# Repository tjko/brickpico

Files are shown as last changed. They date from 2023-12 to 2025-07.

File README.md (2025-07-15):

# Brickpico: Smart PWM LED Controller



Bricpico is a smart PWM LED controller based around [Raspberry Pi Pico](https://www.raspberrypi.com/documentation/microcontrollers/raspberry-pi-pico.html) (RP2040 MCU).
Brickpico is mainly meant to controlling various LED lights on LEGO models, but can be used to control any LED lights (or other small loads).

Brickpico operates as standalone controller that incorporates programmable timer to turn lights on/off on a schedule.
BrickPico is an Open-source hardware (OSHW) project.

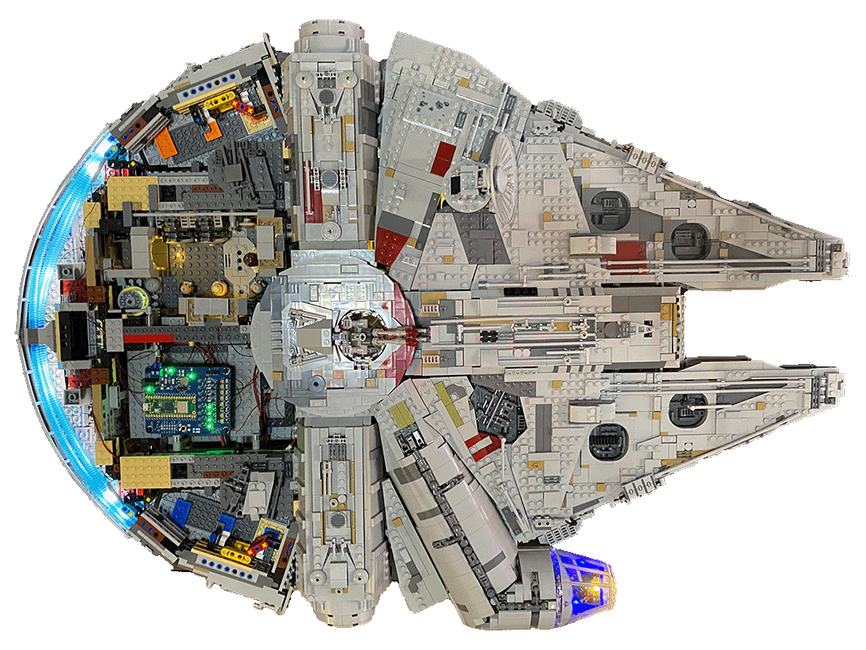
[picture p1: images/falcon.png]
LEGO Millennium Falcon


## Features
* Controls up to 8 to 16 separete channels (LED group)
* Adjustable output brightness (via PWM)
* Adjustable output voltage 5V or 3.3V
* Up to 200mA current output per port (each port has resettable fuse).
* Programmable PWM frequency from 10 to 100000 Hz
* Configurable Lightness/Gamma correction
* Support for configurable lighting "effects" on each channel
* Connectors for common Lego light kits (Light My Bricks, etc.) as well as 2.54mm pin header.
* I2C OLED display module support (128x64 or 128x128)
* I2C Enviromental sensor support (up to 8 sensors)
* Configuration stored on the device itself (in the flash memory).
* SCPI "like" programming interface (see [Command Reference](commands.md))
* WiFi support if opting to mount Pico W on the board.
* HTTP server for monitoring.
* MQTT support for sending status and to receive commands.
* Home Assistant (MQTT Discovery) support
* Telnet server for remote configuration and monitoring.
* SSH server for remote configuration and monitoring.

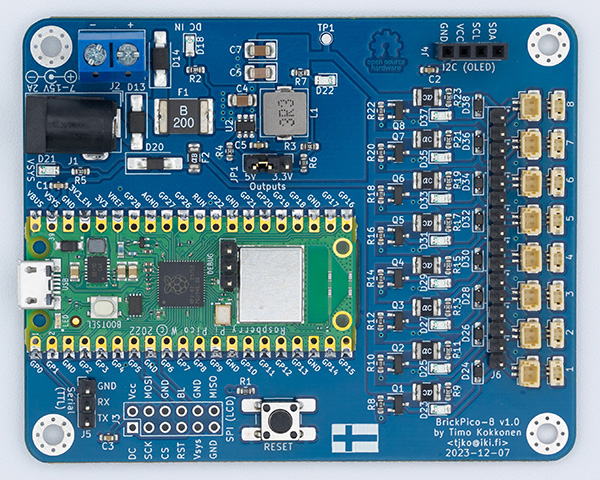
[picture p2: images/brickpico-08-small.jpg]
BrickPico


### Interfaces

* Serial "Console". Primary method for configuring/monitoring FanPico units is via (USB) Serial console (some units also have 3.3V TTL Serial connection).
* Telnet server allows configuration and monitoring over network.
* Web Interface (available when using _Pico W_) over WiFi

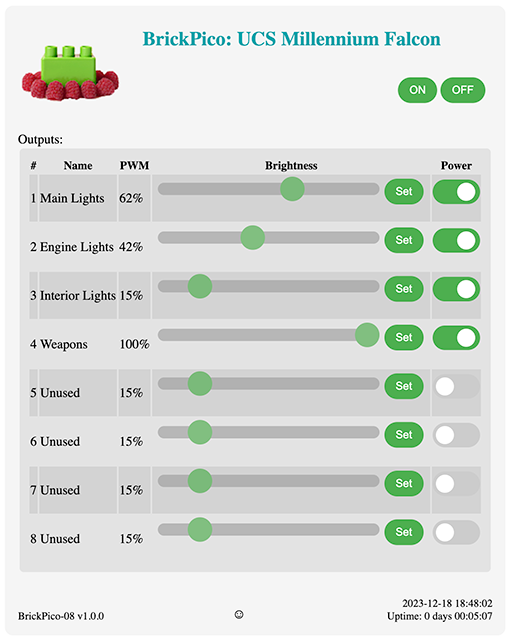
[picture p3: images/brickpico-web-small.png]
BrickPico
   

For more documentation check [BrickPico Wiki](https://github.com/tjko/brickpico/wiki)

## Where can I get one?
Initially BrickPico is only available as a DIY kit. For places to buy kits, check discussions: [Where to Buy BrickPico](https://github.com/tjko/brickpico/discussions/5)

(Instructions for building the kit can be found at: [BrickPico Wiki](https://github.com/tjko/brickpico/wiki)

### DIY Option
You can upload the Kerber files (found under boards directory) to your favorite PCB maker website and get your boards produced in matter of days.
Component list (BOM or bill of materials) is found under boards directory as well along with the electrical schematics.

### Review Units
If you are member of press (or YouTuber) and would like to review/test Brickpico. Please contact me via email.

## How Can I help?
* Build your own BrickPico and provide feedback, suggestions (see discussion forums).
* If you're into electronics new/improved board designs are most welcome.
* If you're into programming:
  - Create cool (desktop) program that allows easily configuring/controlling BrickPico boards.
  - Help improve the firmware.
* If you're into graphics (or web) design:
  - Help create cool (but lightweight) web interface
  - Create better logo for BrickPico
* As this is Open (Source) Hardware Project, if you like to build (and sell) assembled boards or DIY kits, you'd be most welcome...
* You can always donate (and get your name added to the Sponsors section, if you so wish).

## Hardware
BrickPico is Open Source Hardware, reference design is provided for the "08" model (8 outputs) and "16" model (16 outputs).

Additional models with different combinations of fan outputs could be easily designed (takining into account limitations of Raspberry Pi Pico I/O limits). New and improved PCB models/designs are most welcome.

BrickPico is loosely based on FanPico:
* [FanPico](https://github.com/tjko/fanpico/) - Open Source Smart PWM (PC) Fan Controller.

### Models (PCB designs)
Currently following models are available:

|Model|Outputs|Notes|
|-----|---|-----|
|[BRICKPICO-08](boards/brickpico-8/)|8||
|[BRICKPICO-16](boards/brickpico-16/)|16|PCB under development|

## Firmware
Firmware is developed in C using the Pico SDK. Pre-compiled firmware is released when there is new major features or bug fixes.

Latest pre-compiled firmware image can be found here: [Releases](https://github.com/tjko/brickpico/releases)

To get latest firmware with latest updates/fixes you must compile the firmware from the sources.

### Installing firmware image
Firmware can be installed via the built-in UF2 bootloader on the Raspberry Pi Pico or using the debug header with Picoprobe, etc...

#### Selecting Right Firmware to use
Each release (zip file) contains multiple different firmware files.
Make sure to select firmware for the board you're using and for the pico model ("pico_w" if using Pico W).

Firmware file names have format: brickpico-<board_model>-<pico_model>.uf2
```
brickpico-08-pico.uf2
brickpico-08-pico_w.uf2
brickpico-16-pico.uf2
brickpico-16-pico_w.uf2
```

#### Upgrading Firmware
Firmware upgrade steps:
* Boot Pico into UF2 bootloader. This can be done in two ways:
  1)  Press and hold "bootsel" button and then press and release "reset" button.
  2)  Issue command: SYS:UPGRADE
* Copy firmware file to the USB mass storage device that appears.
* As soon as firmware copy is complete, Pico will reboot and run the fanpico firmware.

### Building Firmware Images

Raspberry Pi Pico C/C++ SDK is required for compiling the firmware:

#### Requirements / Dependencies
* [Raspberry Pi Pico C/C++ SDK](https://www.raspberrypi.com/documentation/microcontrollers/c_sdk.html)
* [cJSON](https://github.com/DaveGamble/cJSON)
* [pico-lfs](https://github.com/tjko/pico-lfs)
* [ss_oled-lib](https://github.com/tjko/ss_oled-lib)
* [libb64](https://github.com/libb64/libb64)
* [pico-telnetd](https://github.com/tjko/pico-telnetd)

##### Install Pico SDK
Pico SDK must be installed working before you can compile fanpico.

Instructions on installing Pico SDK see: [Getting started with Raspberry Pi Pico](https://datasheets.raspberrypi.com/pico/getting-started-with-pico.pdf)

(Make sure PICO_SDK_PATH environment variable is set)

##### Downloading sources

Create some directory for building fanpico ('src' used in this example):
```
$ mkdir src
$ cd src
$ git clone https://github.com/tjko/brickpico.git
$ git submodule update --init --recursive
```

##### Building fanpico firmware

To build brickpico firmware, first create a build directory:
```
$ cd brickpico
$ mkdir build
```

Select which board to build firmware for (default is "08") and which Pico is to be used (default is "pico_w"):
```
$ cd build
$ cmake -DBRICKPICO_BOARD=16 -DPICO_BOARD=pico_w ..
```

Then compile fanpico:
```
$ make -j
```

After successful compile you should see firmware binary in the build directory:
subdirectory:

```
$ ls *.uf2
brickpico.uf2
```

If you have picotool installed you can check the firmware image information:
```
$ picotool info -a brickpico.uf2
File brickpico.uf2 family ID 'rp2040':

Program Information
 name:              brickpico
 version:           1.4.0beta
 web site:          https://github.com/tjko/brickpico/
 description:       BrickPico-08 - Smart LED Controller
 features:          USB stdin / stdout
 boot settings:     bootdelay = 0
                    safemode = 0
 binary start:      0x10000000
 binary end:        0x1010b638
 embedded drive:    0x101c0000-0x10200000 (256K): littlefs

Fixed Pin Information
 0:                 TX (Serial)
 1:                 RX (Serial)
 2:                 SCK (SPI)
 3:                 MOSI (SPI)
 4:                 MISO (SPI)
 5:                 CS (SPI)
 6:                 PWM7 signal (output)
 7:                 PWM8 signal (output)
 16:                PWM1 signal (output)
 17:                PWM2 signal (output)
 18:                PWM3 signal (output)
 19:                PWM4 signal (output)
 20:                PWM5 signal (output)
 21:                PWM6 signal (output)
 22:                LCD DC (SPI)
 26:                SDA (I2C)
 27:                SCL (I2C)
 28:                LCD Reset (SPI)

Build Information
 sdk version:       2.1.1
 pico_board:        pico_w
 boot2_name:        boot2_w25q080
 build date:        Jul 14 2025
 build attributes:  Release

Metadata Blocks
 none
```

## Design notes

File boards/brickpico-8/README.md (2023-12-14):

# BRICKPICO-08 PCB

PCB Size: 86mm x 79.5mm

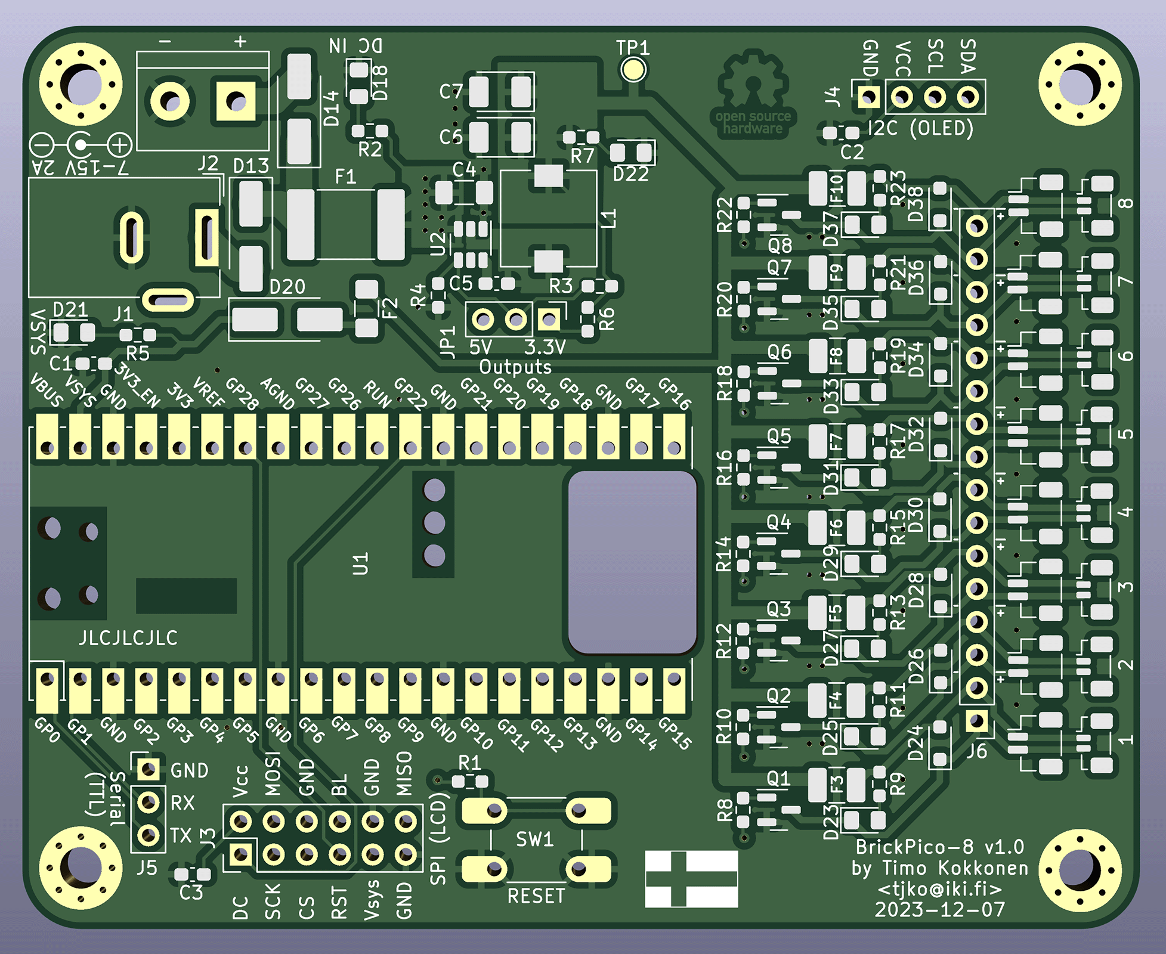
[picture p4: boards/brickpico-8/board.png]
PCB Render


## Change Log

v1.0 
- First Prototye

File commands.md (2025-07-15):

# BrickPico: Command Reference
BrickPico uses "SCPI like" command set. Command syntax should be mostly SCPI and IEE488.2 compliant,
to make it easier to control and configure Fanpico units.

## Command Set
BrickPico supports following commands:

* [*IDN?](#idn)
* [*RST](#rst)
* [CONFigure?](#configure)
* [CONFigure:DEFault:PWM](#configuredefaultpwm)
* [CONFigure:DEFault:STAte](#configuredefaultstate)
* [CONFigure:DELete](#configuredelete)
* [CONFigure:Read?](#configureread)
* [CONFigure:SAVe](#configuresave)
* [CONFigure:OUTPUTx:NAME](#configureoutputxname)
* [CONFigure:OUTPUTx:NAME?](#configureoutputxname-1)
* [CONFigure:OUTPUTx:EFFect](#configureoutputxeffect)
* [CONFigure:OUTPUTx:EFFect?](#configureoutputxeffect-1)
* [CONFigure:OUTPUTx:MINpwm](#configureoutputxminpwm)
* [CONFigure:OUTPUTx:MINpwm?](#configureoutputxminpwm-1)
* [CONFigure:OUTPUTx:MAXpwm](#configureoutputxmaxpwm)
* [CONFigure:OUTPUTx:MAXpwm?](#configureoutputxmaxpwm-1)
* [CONFigure:OUTPUTx:PWM](#configureoutputxpwm)
* [CONFigure:OUTPUTx:PWM?](#configureoutputxpwm-1)
* [CONFigure:OUTPUTx:STAte](#configureoutputxstate)
* [CONFigure:OUTPUTx:STAte?](#configureoutputxstate-1)
* [CONFigure:TIMERS?](#configuretimers)
* [CONFigure:TIMERS:ADD](#configuretimersadd)
* [CONFigure:TIMERS:DEL](#configuretimersdel)
* [CONFigure:VSENSORS?](#configurevsensors)
* [CONFigure:VSENSORS:SOUrces?](#configurevsensorssources)
* [CONFigure:VSENSORx:NAME](#configurevsensorxname)
* [CONFigure:VSENSORx:NAME?](#configurevsensorxname-1)
* [CONFigure:VSENSORx:SOUrce](#configurevsensorxsource)
* [CONFigure:VSENSORx:SOUrce?](#configurevsensorxsource-1)
* [MEASure:Read?](#measureread)
* [MEASure:OUTPUTx?](#measureoutputx)
* [MEASure:OUTPUTx:Read?](#measureoutputxread)
* [MEASure:OUTPUTx:PWM](#measureoutputxpwm)
* [MEASure:VSENSORS?](#measurevsensors)
* [MEASure:VSENSORx?](#measurevsensorx)
* [MEASure:VSENSORx:HUMidity?](#measurevsensorxhumidity)
* [MEASure:VSENSORx:PREssure?](#measurevsensorxpressure)
* [MEASure:VSENSORx:Read?](#measurevsensorxread)
* [MEASure:VSENSORx:TEMP?](#measurevsensorxtemp)
* [Read?](#read)
* [SYStem:ERRor?](#systemerror)
* [SYStem:DEBug](#systemdebug)
* [SYStem:DEBug?](#systemdebug-1)
* [SYStem:GAMMA](#systemgamma)
* [SYStem:GAMMA?](#systemgamma-1)
* [SYStem:LOG](#systemlog)
* [SYStem:LOG?](#systemlog-1)
* [SYStem:SYSLOG](#systemsyslog)
* [SYStem:SYSLOG?](#systemsyslog-1)
* [SYStem:DISPlay](#systemdisplay)
* [SYStem:DISPlay?](#systemdisplay)
* [SYStem:DISPlay:LAYOUTR](#systemdisplaylayoutr)
* [SYStem:DISPlay:LAYOUTR?](#systemdisplaylayoutr-1)
* [SYStem:DISPlay:LOGO](#systemdisplaylogo)
* [SYStem:DISPlay:LOGO?](#systemdisplaylogo-1)
* [SYStem:DISPlay:THEMe](#systemdisplaytheme)
* [SYStem:DISPlay:THEMe?](#systemdisplaytheme-1)
* [SYStem:ECHO](#systemecho)
* [SYStem:ECHO?](#systemecho-1)
* [SYStem:FLASH?](#systemflash)
* [SYStem:I2C?](#systemi2c)
* [SYStem:I2C:SCAN?](#systemi2cscan)
* [SYStem:I2C:SPEED](#systemi2cspeed)
* [SYStem:I2C:SPEED?](#systemi2cspeed?)
* [SYStem:OUTputs?](#systemoutputs)
* [SYStem:LED](#systemled)
* [SYStem:LED?](#systemled-1)
* [SYStem:LFS?](#systemlfs)
* [SYStem:LFS:COPY](#systemlfscopy)
* [SYStem:LFS:DELete](#systemlfsdelete)
* [SYStem:LFS:DIR?](#systemlfsdir)
* [SYStem:LFS:FORMAT](#systemlfsformat)
* [SYStem:LFS:REName](#systemlfsrename)
* [SYStem:MEM](#systemmem)
* [SYStem:MEM?](#systemmem-1)
* [SYStem:MQTT:SERVer](#systemmqttserver)
* [SYStem:MQTT:SERVer?](#systemmqttserver-1)
* [SYStem:MQTT:PORT](#systemmqttport)
* [SYStem:MQTT:PORT?](#systemmqttport-1)
* [SYStem:MQTT:USER](#systemmqttuser)
* [SYStem:MQTT:USER?](#systemmqttuser-1)
* [SYStem:MQTT:PASSword](#systemmqttpassword)
* [SYStem:MQTT:PASSword?](#systemmqttpassword-1)
* [SYStem:MQTT:SCPI](#systemmqttscpi)
* [SYStem:MQTT:SCPI?](#systemmqttscpi-1)
* [SYStem:MQTT:TLS](#systemmqtttls)
* [SYStem:MQTT:TLS?](#systemmqtttls-1)
* [SYStem:MQTT:HA:DISCovery](#systemmqtthadiscovery)
* [SYStem:MQTT:HA:DISCcovery?](#systemmqtthadiscovery-1)
* [SYStem:MQTT:INTerval:STATus](#systemmqttintervalstatus)
* [SYStem:MQTT:INTerval:STATus?](#systemmqttintervalstatus-1)
* [SYStem:MQTT:INTerval:TEMP](#systemmqttintervaltemp)
* [SYStem:MQTT:INTerval:TEMP?](#systemmqttintervaltemp-1)
* [SYStem:MQTT:INTerval:PWM](#systemmqttintervalpwm)
* [SYStem:MQTT:INTerval:PWM?](#systemmqttintervalpwm-1)
* [SYStem:MQTT:TOPIC:STATus](#systemmqtttopicstatus)
* [SYStem:MQTT:TOPIC:STATus?](#systemmqtttopicstatus-1)
* [SYStem:MQTT:TOPIC:COMMand](#systemmqtttopiccommand)
* [SYStem:MQTT:TOPIC:COMMand?](#systemmqtttopiccommand-1)
* [SYStem:MQTT:TOPIC:RESPonse](#systemmqtttopicresponse)
* [SYStem:MQTT:TOPIC:RESPonse?](#systemmqtttopicresponse-1)
* [SYStem:MQTT:TOPIC:ERRor](#systemmqtttopicerror)
* [SYStem:MQTT:TOPIC:ERRor?](#systemmqtttopicerror-1)
* [SYStem:MQTT:TOPIC:WARNing](#systemmqtttopicwarning)
* [SYStem:MQTT:TOPIC:WARNing?](#systemmqtttopicwarning-1)
* [SYStem:MQTT:TOPIC:TEMP](#systemmqtttopictemp)
* [SYStem:MQTT:TOPIC:TEMP?](#systemmqtttopictemp-1)
* [SYStem:MQTT:TOPIC:PWM](#systemmqtttopicpwm)
* [SYStem:MQTT:TOPIC:PWM?](#systemmqtttopicpwm-1)
* [SYStem:NAME](#systemname)
* [SYStem:NAME?](#systemname-1)
* [SYStem:PWMfreq](#systempwmfreq)
* [SYStem:PWMfreq?](#systempwmfreq-1)
* [SYStem:SERIAL](#systemserial)
* [SYStem:SERIAL?](#systemserial-1)
* [SYStem:SPI](#systemspi)
* [SYStem:SPI?](#systemspi-1)
* [SYStem:SSH:SERVer](#systemsshserver)
* [SYStem:SSH:SERVer?](#systemsshserver-1)
* [SYStem:SSH:AUTH](#systemsshauth)
* [SYStem:SSH:AUTH?](#systemsshauth-1)
* [SYStem:SSH:PORT](#systemsshport)
* [SYStem:SSH:PORT?](#systemsshport-1)
* [SYStem:SSH:USER](#systemsshuser)
* [SYStem:SSH:USER?](#systemsshuser-1)
* [SYStem:SSH:PASSword](#systemsshpassword)
* [SYStem:SSH:PASSword?](#systemsshpassword-1)
* [SYStem:SSH:KEY?](#systemsshkey)
* [SYStem:SSH:KEY:CREate](#systemsshkeycreate)
* [SYStem:SSH:KEY:DELete](#systemsshkeydelete)
* [SYStem:SSH:KEY:LIST?](#systemsshkeylist)
* [SYStem:SSH:PUBKEY?](#systemsshpubkey)
* [SYStem:SSH:PUBKEY:ADD](#systemsshpubkeyadd)
* [SYStem:SSH:PUBKEY:DELete](#systemsshpubkeydelete)
* [SYStem:SSH:PUBKEY:LIST?](#systemsshpubkeylist)
* [SYStem:TELNET:SERVer](#systemtelnetserver)
* [SYStem:TELNET:SERVer?](#systemtelnetserver-1)
* [SYStem:TELNET:AUTH](#systemtelnetauth)
* [SYStem:TELNET:AUTH?](#systemtelnetauth-1)
* [SYStem:TELNET:PORT](#systemtelnetport)
* [SYStem:TELNET:PORT?](#systemtelnetport-1)
* [SYStem:TELNET:RAWmode](#systemtelnetrawmode)
* [SYStem:TELNET:RAWmode?](#systemtelnetrawmode-1)
* [SYStem:TELNET:USER](#systemtelnetuser)
* [SYStem:TELNET:USER?](#systemtelnetuser-1)
* [SYStem:TELNET:PASSword](#systemtelnetpassword)
* [SYStem:TELNET:PASSword?](#systemtelnetpassword-1)
* [SYStem:TIME](#systemtime)
* [SYStem:TIME?](#systemtime-1)
* [SYStem:TIMEZONE](#systemtimezone)
* [SYStem:TIMEZONE?](#systemtimezone-1)
* [SYStem:TLS:CERT](#systemtlscert)
* [SYStem:TLS:CERT?](#systemtlscert-1)
* [SYStem:TLS:PKEY](#systemtlspkey)
* [SYStem:TLS:PKEY?](#systemtlspkey-1)
* [SYStem:UPTIme?](#systemuptime)
* [SYStem:UPGRADE](#systemupgrade)
* [SYStem:VERsion?](#systemversion)
* [SYStem:VSENSORS?](#systemvsensors)
* [SYStem:WIFI?](#systemwifi)
* [SYStem:WIFI:AUTHmode](#systemwifiauthmode)
* [SYStem:WIFI:AUTHmode?](#systemwifiauthmode-1)
* [SYStem:WIFI:COUntry](#systemwificountry)
* [SYStem:WIFI:COUntry?](#systemwificountry-1)
* [SYStem:WIFI:HOSTname](#systemwifihostname)
* [SYStem:WIFI:HOSTname?](#systemwifihostname-1)
* [SYStem:WIFI:IPaddress](#systemwifiipaddress)
* [SYStem:WIFI:IPaddress?](#systemwifiipaddress-1)
* [SYStem:WIFI:MODE](#systemwifimode)
* [SYStem:WIFI:MODE?](#systemwifimode-1)
* [SYStem:WIFI:NETMASK](#systemwifinetmask)
* [SYStem:WIFI:NETMASK?](#systemwifinetmask-1)
* [SYStem:WIFI:GATEWAY](#systemwifigateway)
* [SYStem:WIFI:GATEWAY?](#systemwifigateway-1)
* [SYStem:WIFI:NTP](#systemwifintp)
* [SYStem:WIFI:NTP?](#systemwifintp-1)
* [SYStem:WIFI:SYSLOG](#systemwifisyslog)
* [SYStem:WIFI:SYSLOG?](#systemwifisyslog-1)
* [SYStem:WIFI:MAC?](#systemwifimac)
* [SYStem:WIFI:SSID](#systemwifissid)
* [SYStem:WIFI:SSID?](#systemwifissid-1)
* [SYStem:WIFI:STATus?](#systemwifistatus)
* [SYStem:WIFI:STATS?](#systemwifistats)
* [SYStem:WIFI:PASSword](#systemwifipassword)
* [SYStem:WIFI:PASSword?](#systemwifipassword-1)
* [WRIte:OUTPUTx](#writeoutputx)
* [WRIte:OUTPUTx:PWM](#writeoutputxpwm)
* [WRIte:OUTPUTx:STAte](#writeoutputxstate)
* [WRIte:VSENSORx](#writevsensorx)

Additionally unit will respond to following standard SCPI commands to provide compatibility in case some program
unconditionally will send these:
* *CLS
* *ESE
* *ESE?
* *ESR?
* *OPC
* *OPC?
* *SRE
* *SRE?
* *STB?
* *TST?
* *WAI

### Common Commands

#### *IDN?
Identify device. This returns string that contains following fields:
```
<manufacturer>,<model number>,<serial number>,<firmware version>
```

Example:
```
*IDN?
TJKO Industries,BRICKPICO-16,e660c0d1c768a330,1.0
```

#### *RST
Reset unit. This triggers BrickPico to perform (warm) reboot.

```
*RST
```

### CONFigure:
Commands for configuring the device settings.

#### CONFigure?
Display current configuration in JSON format.
Same as CONFigure:Read?

Example:
```
CONF?
```

#### CONFigure:DEFault:PWM
Copy current output PWM (brightess) settings to power-on default PWM settings.
Alternative to this command is to set default PWM for each port using _CONF:OUTPUTx:PWM_ command.

Configuration must be saved after running this command.

Example:
```
CONF:DEFAULT:PWM
CONF:SAVE
```

#### CONFigure:DEFault:STAte
Copy current output states (ON/OFF) to power-on default states.
Alternative to this command is to set default power on state using _CONF:OUTPUTx:DEFAULT_ command.

Configuration must be saved after running this command.

Example:
```
CONF:DEFAULT:STATE
CONF:SAVE
```

#### CONFigure:DELete
Delete current configuration saved into flash. After unit has been reset it will be using default configuration.

Example:
```
CONF:DEL
*RST
```

#### CONFigure:Read?
Display current configuration in JSON format.

Example:
```
CONF:READ?
```

#### CONFigure:SAVe
Save current configuration into flash memory.

Example:
```
CONF:SAVE
```

### CONFigure:OUTPUTx Commands
OUTPUTx commands are used to configure specific output port.
Where x is a number for the output port.

For example:
```
CONFIGURE:OUTPUT8:NAME Interrior Lights
```

#### CONFigure:OUTPUTx:NAME
Set name for output port.

For example:
```
CONF:OUTPUT1:NAME Front Lights
```

#### CONFigure:OUTPUTx:NAME?
Query name of a output port.

For example:
```
CONF:OUTPUT1:NAME?
Front Lights
```

#### CONFigure:OUTPUTx:EFFect
Configure active effect for an ouput channgel.

Effect|Description|Arguments|Argument Descriptions|Default|Notes
------|-----------|---------|---------------------|-------|-------
none|No effect|||
fade|Fade in/out when channgel is toggled on/off.|fade_in_time,fade_out_time|Fade-in and fade-out times in seconds.|fade,1.0,1.0|
blink|Blink output at specified rate.|on_time,off_time|Light on and off times in seconds.|blink,0.5,1.5|
pulse|Pulse output|fade_in_time,on_time,fade_out_time,off_time|Define duration of each 4 sections of a pulse "cycle" inseconds.|fade,2.0,0.5,2.0,0.5|

For example (configur blinking using defaults):
```
CONF:OUTPUT1:EFF blink
```

For example (configure blinking with custom parameters):
```
CONF:OUTPUT1:EFF blink,1.0,2.5
```

#### CONFigure:OUTPUTx:EFFect?
Display currently active effect for an output.

Format: effect,arg_1,arg_2,...arg_n

For example:
```
CONF:OUTPUT1:EFF?
blink,0.500000,1.500000
```

#### CONFigure:OUTPUTx:MINpwm
Set absolute minimum PWM duty cycle (%) for given output port.
This can be used to make sure that output never sees a lower
duty cycle (overriding the normal signal).

Default: 0 %

Example: Set minimum PWM duty cycle to 20% for OUTPUT1
```
CONF:OUTPUT1:MIN 20
```

#### CONFigure:OUTPUTx:MINpwm?
Query current minimum PWM duty cycle (%) configured on a output port.

Example:
```
CONF:OUTPUT1:MIN?
20
```

#### CONFigure:OUTPUTx:MAXpwm
Set absolute maximum PWM duty cycle (%) for given output port.
This can be used to make sure that output never sees higher duty cycle
than given value (overriding the normal output signal).

Default: 100 %

Example: Set maximum PWM duty cycle to 95% for OUTPUT1
```
CONF:OUTPUT1:MAX 95
```

#### CONFigure:OUTPUTx:MAXpwm?
Query current maximum PWM duty cycle (%) configured on a output port.

Example:
```
CONF:OUTPUT1:MAX?
95
```

#### CONFigure:OUTPUTx:PWM
Set default PWM duty cycle (%) for given output port.
This is value set when unit boots up and normally defaults
to 100% (full brightness).

Default: 100%

Example: Set default PWM duty cycle to 50% for OUTPUT1
```
CONF:OUTPUT1:PWM 50
```

#### CONFigure:OUTPUTx:PWM?
Query current default PWM duty cycle for an output port.

Example:
```
CONF:OUTPUT1:PWM?
50
```

#### CONFigure:OUTPUTx:STAte
Controls whether output is ON or OFF state when unit boots up.

Values: ON, OFF

Default: OFF

Example: Set Output 5 to be ON when system boots up.
```
CONF:OUTPUT5:STATE ON
```

#### CONFigure:OUTPUTx:STAte?
Query whether output is set to default to ON or OFF when unit boots up.

Example:
```
CONF:OUTPUT1:STATE?
OFF
```

#### CONFigure:TIMERS?
List currently configured timers (events).

Output format:
```
<#>: <minute> <hour> <weekdays> <action> <outputs> <comment>
```

Example:
```
CONF:TIMERS?
1: 00 18 1-5 ON 1-6 turn on lights during the week
1: 00 17 6-7 ON 1-6 turn on lights on the weekends
2: 30 05 0-6 OFF 1-16 turn off lights in the morning
```

#### CONFigure:TIMERS:ADD
Add new timer entry.

Timer entry format:
```
<minute> <hour> <weekdays> <action> <outputs> [<comment>]
```

Field|Valid Values|Description
-----|------|-----
minute|00..59|Minute
hour|00.23|Hour (24h clock)
weekdays|0..6|0=Sunday, 1=Monday, 2=Tuesday, ... 6=Saturday
action|ON, OFF|
outputs|1..n|Outputs that the event affects.

Specifying _weekdays_ and _outputs_:

Notation|Description
--------|-----------
*|Match all
1,3,5|List
1-5|Range

Example:
```
CONF:TIMERS:ADD 00 18 1-5 ON 1-6 Turn on during the week
CONF:TIMERS:ADD 00 17 6-7 ON 1-8 Turn on during weekends
CONF:TIMERS:ADD 00 06 * OFF * Turn everything off in the morning 
```

#### CONFigure:TIMERS:DEL
Remove timer event. Command takes the event number as parameter.
Currently configured timer events along with their numbers can be
viewed using: _CONF:TIMERS?_

Example (remove second timer event):
```
CONF:TIMERS:DEL 2
```

#### CONFigure:VSENSORS?

This is same as CONFigure::VSENSORS:SOUrces? command.

#### CONFigure:VSENSORS:SOUrces?
Return virtual sensor (source) configuration information for all
virtual sensors in CSV format.

Format: <vsensor>,<type>,<parameter1>,<parameter2>,...

Example:
```
CONF:VSENSORS:SOURCES?
vsensor1,picotemp
vsensor2,i2c,0x48,TMP117
vsensor3,i2c,0x37,PCT2075
vsensor4,i2c,0x77,DPS310
vsensor5,i2c,0x76,BMP280
vsensor6,i2c,0x49,ADT7410
vsensor7,i2c,0x38,AHT2x
vsensor8,manual,0.00,30
```

### CONFigure:VSENSORx Commands
VSENSORx (where x is the sensor number) commands are used to configure virtual temperature sensors.
These can be "sensors" that are updated by software, like "CPU Temperature" of host system.
Or these can be be virtual sensors that report value of multiple physical sensors fed through a mathematical formula.

Where x is a number from 1 to 8.

Virtual Sensor Mode|Description
------|-----------
manual|Manually updated (by software) sensor values. For example host CPU Temperature.
max|Maximum temperature of configured source sensors.
min|Minimum temperature of configured source sensors.
avg|Average temperature of configured source sensors.
delta|Temperature delta between readings from two source sensors.
i2c|Reading from digital I2C sensor.
picotemp|Pico (MCU) Temperature.

#### CONFigure:VSENSORx:NAME
Set name for virtual temperature sensor.

For example:
```
CONF:VSENSOR1:NAME Pico Temperature
```

#### CONFigure:VSENSORx:NAME?
Query name of a virtual temperature sensor.

For example:
```
CONF:VSENSOR1:NAME?
Pico Temperature
```

#### CONFigure:VSENSORx:SOUrce
Configure source for the virtual temperature sensor.

Source types:

MODE|Description|No of Parameters|Parameters
----|-----------|----------------|----------
MANUAL|Temperature updated by external program/driver|2|default_temperature_C,timeout
MAX|Maximum temperatore between source sensors|2+|sensor_a,sensor_b, ...
MIN|Minimum temperature between source sensors|2+|sensor_a,sensor_b, ...
AVG|Average temperature between source sensors|2+|sensor_a,sensor_b, ...
DELTA|Temperature delta between to source sensors|2|sensor_a,sensor_b
I2C|Temperature reading from digital I2C sensor|2|i2c_address,sensor_type_or_alias
PICOTEMP|Pico (MCU) temperature|0|

Note, in "manual" mode if timeout_ms is set to zero, then sensor's temperature reading
will never revert back to default value (if no updates are being received).

Sensor numbering:
 - VSENSORS: 1, 2, ...
 - PICO Temperature: 101

Supported I2C sensors:

Sensor Type|Aliases|Possible Addresses|Description|Notes
-----------|-------|------------------|-----------|-----
ADT7410||0x48, 0x49, 0x4a, 0x4b|16bit Digital Temperature Sensor, 0.5C accuracy
AHT1x|||AHT1x Series Temperature and Humidity sensors (AHT10, AHT11 ,...)
AHT2x|||AHT2x Series Temperature and Humidity sensors (AHT20, AHT21 ,...)
AM2320||0x5c|Temperature and Humidity Sensor, 0.5C accuracy|Not found when scanning bus. May not work above 100kHz bus speeds.
AS621x|AS6212, AS6214, AS6218||AS621x Series sensors: AS6212 (0.2C), AS6214 (0.4C), AC6218 (0.8C)
BMP180|||16bit, 0.5C accuracy
BMP280||0x76, 0x77|20bit, 0.5C accuracy
DPS310||0x77, 0x76|24bit, 0.5C accuracy
HDC302x|HDC3022, HDC3021, HDC3020|0x44, 0x45, 0x46, 0x47|HDC302x Series Temperature and Humiditysensors
HTS221||0x5f|Temperature and Humidity Sensor
HTU21D||0x40|Temperature and Humidity Sensor, 0.4C accuracy|Not found when scanning bus (SYS:I2C:SCAN?)
HTU31D||0x40, 0x41|Temperature and Humidity Sensor, 0.3C accuracy
LPSxx|LPS22, LPS25, LPS28, LPS33, LPS35|0x5d, 0x5c|LPSxx Series Temperature and Pressure sensors
MCP9808|||Digital Temperature Sensor, 0.5C accuracy
MPL115A2||0x60|Digital Barometer|Temperature sensor not calibrated.
MPL3115A2||0x60|Temperature and Pressure sensor with Altimetry, 1C accuracy
MS5611||0x76, 0x77|Temperature and Pressure Sensor|Not found when scanning bus (SYS:I2C:SCAN?)
MS8607||0x76 and 0x40|Temperature, Humidity and Pressure Sensor|Not found when scanning bus (SYS:I2C:SCAN?), appears as two seprate devices.
PCT2075|||Digital Temperature Sensor, 1C accuracy
SHT3x|SHT30, SHT31, SHT35|0x44, 0x34|SHT3x Series Temperature and Humidity sensors|Not always found when scanning bus (SYS:I2C:SCAN?)
SHT4x|SHT40, SHT41, SHT43, SHT45|0x44|SHT4x Series Temperature and Humidity sensors|Not always found when scanning bus (SYS:I2C:SCAN?)
SHTC3||0x70|Temperature and Humidity sensor, 0.2C accuracy
SI7021||0x40|Temperature and Humidity sensor, 0.4C accuracy
STTS22H||0x38, 0x3c, 0x3e, 0x3f|Temperature Sensor, 0.5C accuracy
TC74|TC74A0|0x48 - 0x4f|Digital Thermal Sensor, 2C accuracy
TMP102||0x48, 0x49, 0x4a, 0x4b|Temperature Sensor, 2C accuracy
TMP117||0x48, 0x49, 0x4a, 0x4b|Temperature Sensor, 0.1C accuracy

Defaults:

Default for all virtual sensors is to be in "MANUAL" mode and revert automatically to 0C
if no temperature update has been received within 30 seconds.

VSENSOR|SOURCE
---|------
1|MANUAL,0,30
...|...

Example: Set VSENSOR1 to report temperature that is updated by external program. And to sensor reading to revert to default value of 99C if no update has been received within 5 seconds.
```
CONF:VSENSOR2:SOURCE manual,99,5
```

Example: Set VSENSOR2 to follow report temperature delta between SENSOR1 and SENSOR2.
```
CONF:VSENSOR2:SOURCE delta,1,2
```

Example: Set VSENSOR3 to report average temperature between SENSOR1, SENSOR2, and VSENSOR1
```
CONF:VSENSOR3:SOURCE avg,1,2,101
```

Example: Set VSENSOR5 to report temperature from TMP117 (I2C) sensor with address 0x48:
```
CONF:VSENSOR5:SOURCE i2c,0x48,tmp117
```

(to get list of currently active I2C sensor addresses, use: SYS:I2C:SCAN?)

#### CONFigure:VSENSORx:SOUrce?
Query a virtual temperature sensor configuration (temperature reading source).

Command returns response in following format:
```
mode,parameter,parameter,...
```

Example:
```
CONF:VSENSOR1:SOU?
manual,99.0,5
```

### MEASure Commands
These commands are for reading (measuring) the current output values on ports.

#### MEASure:Read?
This command returns current output settings on all OUTPUT ports.
(This is same as: Read?)

Response format:
```
output<n>,"<name>",<output duty cycle>,<output state>
```

Example:
```
MEAS:READ?
output1,"Output 1",100.0,OFF
output2,"Output 2",50.00,OFF
output3,"Output 3",50.00,ON
output4,"Output 4",25.00,ON
...
```

### MEASure:OUTPUTx Commands

#### MEASure:OUTPUTx?
Return current output PWM signal duty cycle (%) for a output.

Response format:
```
<duty_cycle>
```

Example:
```
MEAS:OUTPUT1?
100.00
```

#### MEASure:OUTPUTx:Read?
Return current output PWM signal duty cycle (%) for a output.

This is same as: MEASure:OUTPUTx?

#### MEASure:OUTPUTx:PWM?
Return current output PWM signal duty cycle (%) for a output.

This is same as: MEASure:OUTPUTx?

#### MEASure:VSENSORS?
Return all measurements for all virtual sensors.

Format: sensor,temperature_C,humidity_%,pressure_hPa

Example:
```
MEAS:VSENSORS?
vsensor1,"vsensor1",24.4,0,0
vsensor2,"vsensor2",24.9,0,0
vsensor3,"vsensor3",24.8,43,0
vsensor4,"vsensor4",26.5,0,997
vsensor5,"vsensor5",25.1,0,991
vsensor6,"vsensor6",0.0,0,0
vsensor7,"vsensor7",0.0,0,0
vsensor8,"vsensor8",0.0,0,0
```

#### MEASure:VENSORx?
Return current temperature (C) measured by the sensor.

Example:
```
MEAS:VSENSOR1?
25
```

#### MEASure:VSENSORx:HUMidity?
Return current humidity (%) measured by the sensor.

Example:
```
MEAS:VSENSOR1:HUM?
45
```

#### MEASure:VSENSORx:PREssure?
Return current pressure (hPa) measured by the sensor.

Example:
```
MEAS:VSENSOR1:PRE?
1013
```

#### MEASure:VSENSORx:Read?
Return current temperature (C) measured by the sensor.

This is same as: MEASure:VSENSORx?

Example:
```
MEAS:VSENSOR1:R?
25
```

#### MEASure:VSENSORx:TEMP?
Return current temperature (C) measured by the sensor.

This is same as: MEASure:VSENSORx?

Example:
```
MEAS:VSENSOR1:TEMP?
25
```

### Read Commands

#### Read?
This command returns all setting for all OUTPUT ports.
(This is same as: MEASure:Read?)

Response format:
```
output<n>,"<name>",<output duty cycle>
```

Example:
```
MEAS:READ?
output1,"Output 1",100.0
output2,"Output 2",50.00
output3,"Output 3",50.00
output4,"Output 4",0.00
...
```

### SYStem Commands

#### SYStem:ERRor?
Display status from last command.

Example:
```
SYS:ERR?
0,"No Error"
```

#### SYStem:DEBug
Set the system debug level. This controls the logging to the console.

Default: 0   (do not log any debug messages)

Example: Enable verbose debug output
```
SYS:DEBUG 2
```

#### SYStem:DEBug?
Display current system debug level.

Example:
```
SYS:DEBUG?
0
```

#### SYStem:GAMMA
Set system PWM output mapping (Lightness/Gamma correction).

Light output from LED lights normally does not correlate linearly
to PWM duty cycle. PWM output mapping can be used to "correct" this
to produce more linear light (output) compared to PWM duty cycle.

Value|Description|Value Range|Example
---------------|-----------|-----------|------
\<number\>|Gamma correction factor (valid range 1.0 - 10.0)|2.5
cie|CIE (1931) Lightness algorithm|N/A|cie
\<blank\>|Use default correction|N/A|

Default: <blank>   (use default correction method; currently CIE 1931)

Example: Set output PWM mapping to use Gamma 2.2 correction factor
```
SYS:GAMMA 2.2
```

#### SYStem:GAMMA?
Display current system PWM output mapping (Lightness/Gamma correction).

Value|Description
-----|----------
1.0|Gamma correction factor 1.0 (no correction)
2.2|Gamma correction factor 2.2 (slightly under corrected)
2.5|Gamma correction factor 2.5 (normal correction)
cie|Use CIE 1931 Lightness algorithm
\<blank\>|Use default correction (currently "cie")

Example:
```
SYS:GAMMA?
2.5
```

#### SYStem:LOG
Set the system logging level. This controls the level of logging to the console.

Default: WARNING

Log Levels:

Level|Name
-----|----
0|EMERG
1|ALERT
2|CRIT
3|ERR
4|WARNING
5|NOTICE
6|INFO
7|DEBUG

Example: Enable verbose debug output
```
SYS:LOG DEBUG
```

#### SYStem:LOG?
Display current system logging level.

Example:
```
SYS:LOG?
NOTICE
```

#### SYStem:SYSLOG
Set the syslog logging level. This controls the level of logging to a remote
syslog server.

Default: ERR

Log Levels:

Level|Name
-----|----
0|EMERG
1|ALERT
2|CRIT
3|ERR
4|WARNING
5|NOTICE
6|INFO
7|DEBUG

Example: Enable logging of NOTICE (and lower level) message:
```
SYS:LOG NOTICE
```

#### SYStem:SYSLOG?
Display current syslog logging level.

Example:
```
SYS:SYSLOG?
ERR
```

#### SYStem:DISPlay
Set display (module) parameters as a comma separated list.

This can be used to set display module type if cannot be automatically detected.
Additionally this can be used to set some display parameters like brightness.

Default: default

Currently supported values:

Value|Description|Notes
-----|-----------|-----
default|Use default settings (auto-detect).
128x64|OLED 128x64 module installed.|OLED
128x128|OLED 128x128 module installed.|OLED
132x64|OLED 132x64 installed (some 1.3" 128x64 modules need this setting!)|OLED
flip|Flip display (upside down)|OLED
invert|Invert display|OLED
brightness=n|Set display brightness (%) to n (where n=0..100) [default: 50]|OLED

Example: 1.3" (SH1106) module installed that doesn't get detected correctly
```
SYS:DISP 132x64
```

Example: Invert display and set brightnes to 30%
```
SYS:DISP default,invert,brightness=30
```

#### SYStem:DISPlay?
Display current display module setting.

Example:
```
SYS:DISP?
132x64,flip,invert,brightness=75
```

#### SYStem:DISPlay:LAYOUTR
Configure (OLED) Display layout for the right side of the screen.

Layout is specified as a comma delimited string describing what to
display on each row (8 rows available if using 128x64 OLEd module, 10 rows available with 128x128 pixel modules).

Syntax: <R1>,<R2>,...<R8>

Where tow specifications can be one of the following:

Type|Description|Notes
----|-----------|-----
Mn|MBFan input n|n=1..4
Sn|Sensor input n|n=1..3
Vn|Virtual Sensor input n|n=1..8
-|Horizontal Line|
Ltext|Line with "text"|Max length 9 characters.

Default: <not set>

When this setting is not set following defaults are used based
on the OLED module size:

Screen Size|Available Rows|Default Configuration
-----------|--------------|---------------------
128x64|8|M1,M2,M3,M4,-,S1,S2,S3
128x128|10|LMB Inputs,M1,M2,M3,M4,-,LSensors,S1,S2,S3

Example: configure custom theme (for 128x64 display):
```
SYS:DISP:LAYOUTR M1,M2,-,S1,S2,S3,V1,V2
```

#### SYStem:DISPlay:LAYOUTR?
Display currently configured (OLED) Display layout for the right side of the screen.

Example:
```
SYS:DISP:THEME?
M1,M2,-,S1,S2,S3,V1,V2
```

#### SYStem:DISPlay:LOGO
Configure (LCD) Display boot logo.

Currently available logos:

Name|Description
----|-----------
default|Default FanPico boot logo.
custom|Custom boot logo (only available if firmware has been compiled with custom logo included).

Example: configure custom logo
```
SYS:DISP:LOGO custom
```

#### SYStem:DISPlay:LOGO?
Display currently configured (LCD) Display boot logo.

Example:
```
SYS:DISP:LOGO?
default
```

#### SYStem:DISPlay:THEMe
Configure (LCD) Display theme to use.

Default: default

Example: configure custom theme
```
SYS:DISP:THEME custom
```

#### SYStem:DISPlay:THEMe?
Display currently configured (LCD) display theme name.

Example:
```
SYS:DISP:THEME?
default
```

#### SYStem:ECHO
Enable or disaple local echo on the console.
This can be useful if interactively programming BrickPico.

Value|Status
-----|------
0|Local Echo disabled.
1|Local Echo enabled.

Default: 0

Example: enable local echo
```
SYS:ECHO 1
```

Example: disable local echo
```
SYS:ECHO 0
```

#### SYStem:ECHO?
Display local echo status:

Example:
```
SYS:ECHO?
0
```

### SYStem:FLASH?
Returns information about Pico flash memory usage.

Example:
```
SYS:FLASH?
Flash memory size:                     2097152
Binary size:                           683520
LittleFS size:                         262144
Unused flash memory:                   1151488
```

### SYStem:I2C?
Returns status if I2C bus is active (available) currently.
Depending on board model I2C may not be available at all
or may only be available if SPI is not active.

Returns:

status|description
------|-----------
0|I2C Bus not available
1|I2C Bus available

Example:
```
SYS:I2C?
1
```

### SYStem:I2C:SCAN?
Scan I2C Bus for active devices.
This returns addresses of any devices found on I2C bus.

Example:
```
SYS:I2C:SCAN??
Scanning I2C Bus... 0x3c
Device(s) found: 1
```

### SYStem:I2C:SPEED
Set speed that I2C bus operates.
Note, change won't take effect until unit is rebooted.

Speed range: 10000 - 3400000
(speeds over 1000000 may not work reliably)

Default: 1000000  (1000 kHz or 1000 kbit/s)

Example:
```
SYS:I2C:SPEED 1000000
CONF:SAVE
```

### SYStem:I2C:SPEED?
Return currently configured I2C bus speed (Hz or bit/s).

Example:
```
SYS:I2C:SPEED?
1000000
```

#### SYStem:OUTPUTS?
Display number of OUTPUT output ports available.

Example:
```
SYS:OUTPUTS?
8
```

#### SYStem:LED
Set system indicator LED operating mode.

Supported modes:

mode|description
----|-----------
0   | LED blinking slowly  [default]
1   | LED on (continuously)
2   | LED off

Default: 0

Example to set LED to be on continuously:
```
SYS:LED 1
```

#### SYStem:LED?
Query current system LED operating mode.

Example:
```
SYS:LED?
0
```

#### SYStem:LFS?
Display information about the LittleFS filesystem in the flash memory.

Example:
```
SYS:LFS?
Filesystem size:                       262144
Filesystem used:                       24576
Filesystem free:                       237568
Number of files:                       3
Number of subdirectories:              0
```

#### SYStem:LFS:COPY
Copy a file on the flash filesystem (littlefs).
If destination file already exists copy will fail.

Parameters: <sourcefile> <destinationfile>

Example:
```
SYS:LFS:COPY fanpico.cfg fanpico-backup.cfg
```

#### SYStem:LFS:DELete
Delete file from the flash filesystem (littlefs).

parameters: <filename>

Example (delete TLS certificate and private key):
```
SYS:LFS:DEL cert.pem
SYS:LFS:DEL key.pem
```

#### SYStem:LFS:DIR?
List contents of the flash filesystem (littlefs).

Example:
```
SYS:LFS:DIR?
Directory: /

.                                                       <DIR>
..                                                      <DIR>
cert.pem                                                 1286
fanpico.cfg                                              7012
key.pem                                                  1709

```

#### SYStem:LFS:FORMAT
Format flash filesystem. This will erase current configuration (including any TLS certificates saved in flash).

Example (format filesystem and save current configuration):
```
SYS:LFS:FORMAT
CONF:SAVE
```

#### SYStem:LFS:REName
Rename a file on the flash filesystem (littlefs).

Parameters: <oldname> <newname>

Example:
```
SYS:LFS:REN fanpico-backup.cfg fanpico.cfg
```

### SYStem:MEM
Test how much available (heap) memory system currently has.
This does simple test to try to determine what is the largest
block of heap memory that is currently available as well as
try allocating as many as possible small block of memory to determine
roughly the total available heap memory.

This command takes optional 'blocksize' parameter to specify the memory
block size to use in the tests. Default is 1024 bytes.

Example:
```
SYS:MEM 512
Largest available memory block:        114688 bytes
Total available memory:                111104 bytes (217 x 512bytes)
```

### SYStem:MEM?
Returns information about heap and stack size. As well as information
about current (heap) memory usage as returned by _mallinfo()_ system call.

Note,  _mallinfo()_ doesn't "see" all of the available heap memory, unless ```SYS:MEM``` command
has been run first.

Example:
```
SYS:MEM?
Core0 stack size:                      8192
Core1 stack size:                      4096
Heap size:                             136604
mallinfo:
Total non-mmapped bytes (arena):       136604
# of free chunks (ordblks):            2
# of free fastbin blocks (smblks):     0
# of mapped regions (hblks):           0
Bytes in mapped regions (hblkhd):      0
Max. total allocated space (usmblks):  0
Free bytes held in fastbins (fsmblks): 0
Total allocated space (uordblks):      21044
Total free space (fordblks):           115560
Topmost releasable block (keepcost):   114808
```

### SYStem:MQTT Commands
BrickPico has MQTT Client that can be configured to publish (send) periodic status
updates to a topic.
Additionally MQTT Client support subscribing to a "command" topic to listen for commands.
This allows remotely controlling BrickPico.

To enable MQTT at minimum server must be configured. To explicitly disbable MQTT set server
to empty string.

#### SYStem:MQTT:SERVer
Set MQTT server to connect to. This parameter expects a DNS name as argument.

Default: <empty>   (when this setting is empty string, MQTT is explicitly disabled)

Example (configure MQTT server name):
```
SYS:MQTT:SERVER io.adafruit.com
```

Example (disable MQTT):
```
SYS:MQTT:SERVER
```

#### SYStem:MQTT:SERVer?
Query currently set MQTT server name.

Example:
```
SYS:MQTT:SERVER?
io.adafruit.com
```

#### SYStem:MQTT:PORT
Set MQTT server (TCP) port. This setting is needed when MQTT server is not using standard port.
If this setting is not set (value is left to default "0"), then standard MQTT port is used.

- Secure (TLS) Port = 8883
- Insecure Port = 1883

Default: 0   (when this setting is 0 use default MQTT ports)

Example:
```
SYS:MQTT:PORT 9883
```

#### SYStem:MQTT:PORT?
Query currently set MQTT (TCP) port.

If return value is zero (0), then default MQTT port is being used.

Example:
```
SYS:MQTT:PORT?
0
```

#### SYStem:MQTT:USER
Set MQTT username to use when connecting to MQTT server.

Default: <empty>

Example:
```
SYS:MQTT:USER myusername
```

#### SYStem:MQTT:USER?
Query currently set MQTT username.

Example:
```
SYS:MQTT:USER?
myusername
```

#### SYStem:MQTT:PASS
Set MQTT password to use when connecting to MQTT server.

Default: <empty>

Example:
```
SYS:MQTT:PASS mymqttpassword
```

#### SYStem:MQTT:PASS?
Query currently set MQTT password.

Example:
```
SYS:MQTT:PASS?
mymqttpassword
```

#### SYStem:MQTT:SCPI
Configure if SCPI commands will be accepted via MQTT.
This is potentially "dangerous" feature so only enable if you understand
the potential risks allowing device to be remotely configured.

Default: OFF

Example:
```
SYS:MQTT:SCPI ON
```

#### SYStem:MQTT:SCPI?
Query whether SCPI commands are allowed via MQTT.

Example:
```
SYS:MQTT:SCPI?
OFF
```

#### SYStem:MQTT:TLS
Enable/disable use of secure connection mode (TLS/SSL) when connecting to MQTT server.
Default is TLS on to protect MQTT credentials (usename/password).

Default: ON

Example:
```
SYS:MQTT:TLS OFF
```

#### SYStem:MQTT:TLS?
Query whether TLS is enabled or disabled for MQTT.

Example:
```
SYS:MQTT:TLS?
ON
```

#### SYStem:MQTT:HA:DISCovery
Configure Home Assistant MQTT Discovery prefix. This must be set to enable
Home Assistant support/integration in BrickPico.

If this is left to empty (string), then Home Assistant support is disabled.

Default: <empty>

Example (enable Home Assistant support using default prefix):
```
SYS:MQTT:HA:DISC homeassistant
```

#### SYStem:MQTT:HA:DISCovery?
Query currently set Home Assistant MQTT Discovery prefix.

Note, if this is empty, then Home Assistant support is disabled.

Example:
```
SYS:MQTT:HA:DISC?
homeassistant
```

#### SYStem:MQTT:INTerval:STATus
Configure how often unit will publish (send) status message to status topic.
Set this to 0 (seconds) to disable publishing status updates.
Recommended values are 60 (seconds) or higher.

Default: 600  (every 10 minutes)

Example:
```
SYS:MQTT:INT:STAT 3600
```

#### SYStem:MQTT:INTerval:STATus?
Query currently set frequency for publishing unit status information.

Example:
```
SYS:MQTT:INT:STAT?
3600
```

#### SYStem:MQTT:INTerval:TEMP
Configure how often unit will publish (send) status message to temp topic.
Set this to 0 (seconds) to disable publishing temperature updates.
Recommended values are 60 (seconds) or higher.

Default: 60  (every 60 seconds)

Example:
```
SYS:MQTT:INT:TEMP 180
```

#### SYStem:MQTT:INTerval:TEMP?
Query currently set frequency for publishing unit temperature information.

Example:
```
SYS:MQTT:INT:TEMP?
180
```

#### SYStem:MQTT:INTerval:PWM
Configure how often unit will publish (send) status message to PWM topic.
Set this to 0 (seconds) to disable publishing PWM updates.
Recommended values are 60 (seconds) or higher.

Default: 600  (every 10 minutes)

Example:
```
SYS:MQTT:INT:PWM 300
```

#### SYStem:MQTT:INTerval:PWM?
Query currently set frequency for publishing unit PWM information.

Example:
```
SYS:MQTT:INT:PWM?
300
```

#### SYStem:MQTT:TOPIC:STATus
Configure topic to publish unit status information periodically.
If this is left to empty (string), then no status information is published to MQTT server.

Default: <empty>

Example:
```
SYS:MQTT:TOPIC:STAT musername/feeds/brickpico1
```

#### SYStem:MQTT:TOPIC:STATus?
Query currently set topic for publishing unit status information to.

Example:
```
SYS:MQTT:TOPIC:STAT?
myusername/feeds/brickpico1
```

#### SYStem:MQTT:TOPIC:COMMand
Configure topic to subscribe to to wait for commands to control outputs.
If this is left to empty (string), then unit won't subcrible (and accept) any commands from MQTT.

Default: <empty>

Example:
```
SYS:MQTT:TOPIC:COMM musername/feeds/cmd
```

#### SYStem:MQTT:TOPIC:COMMand?
Query currently set topic for subscribing to wait for commands.

Example:
```
SYS:MQTT:TOPIC:COMM?
myusername/feeds/cmd
```

#### SYStem:MQTT:TOPIC:RESPonse
Configure topic to publish responses to commands received from the command topic.
If this is left to empty, then unit won't send response to any commands.

Default: <empty>

Example:
```
SYS:MQTT:TOPIC:RESP musername/feeds/response
```

#### SYStem:MQTT:TOPIC:RESPonse?
Query currently set topic for publishing responses to commands.

Example:
```
SYS:MQTT:TOPIC:RESP?
myusername/feeds/response
```

#### SYStem:MQTT:TOPIC:ERRor
Configure topic to subscribe to for receiving error messages from MQTT broker.

Default: <empty>

Example:
```
SYS:MQTT:TOPIC:ERR mysername/errors
```

#### SYStem:MQTT:TOPIC:ERRor?
Query currently set topic for subscribing to receive error messages from MQTT broker.

Example:
```
SYS:MQTT:TOPIC:ERR?
myusername/errors
```

#### SYStem:MQTT:TOPIC:WARNing
Configure topic to subscribe to for receiving warning messages from MQTT broker.

Default: <empty>

Example:
```
SYS:MQTT:TOPIC:WARN mysername/throttle
```

#### SYStem:MQTT:TOPIC:WARNing?
Query currently set topic for subscribing to receive warning messages from MQTT broker.

Example:
```
SYS:MQTT:TOPIC:WARN?
myusername/throttle
```

#### SYStem:MQTT:TOPIC:TEMP
Configure topic to publish unit temperature data to.

Default: <empty>

Example:
```
SYS:MQTT:TOPIC:TEMP mysername/feeds/brickpico_temp
```

#### SYStem:MQTT:TOPIC:TEMP?
Query currently set topic for publishing temperature data.

Example:
```
SYS:MQTT:TOPIC:TEMP?
myusername/feeds/brickpico_temp
```

#### SYStem:MQTT:TOPIC:PWM
Configure topic to publish output port PWM status to.
This is a template string where ```%d``` should be used to mark the output port number.

Default: <empty>

Example:
```
SYS:MQTT:TOPIC:PWM mysername/feeds/brickpico_output%d
```

#### SYStem:MQTT:TOPIC:PWM?
Query currently set topic for publishing PWM data.

Example:
```
SYS:MQTT:TOPIC:PWM?
myusername/feeds/brickpico_output%d
```

#### SYStem:NAME
Set name of the system. (Default: fanpico1)

Example:
```
SYS:NAME HomeServer
```

#### SYStem:NAME?
Get name of the system.

Example:
```
SYS:NAME?
HomeServer
```

#### SYStem:PWMfreq
Set PWM frequency for the outputs. Supported range 10Hz - 100kHz.
When changing the frequency, chang will take effect after unit has been rebooted.

Default: 1000  (1kHz)

Example, set PWM frequency to 1.5kHz:
```
SYS:PWM 1500
CONF:SAVE
*RST
```

#### SYStem:PWMfreq?
Get current PWM frequency for the outputs.

Example:
```
SYS:PWM?
1000
```

#### SYStem:SERIAL
Enable or disable TTL Serial Console. This is enabled by default if board has this connector.
Reason to disable this could be to use the second I2C bus that is sharing pins with the UART.

Example (disable serial console):
```
SYS:SERIAL 0
```

#### SYStem:SERIAL?
Return status of TTL Serial Console.

Status|Description
------|-----------
1|Enabled
0|Disabled

Example:
```
SYS:SERIAL?
1
```

#### SYStem:SPI
Enable or disable SPI bus (on connector J18). When SPI bus is enabled I22 (OLED display) and Serial TTL connectors cannot be used
as these share pins with the SPI bus.
Reason to enable SPI bus would be to connect LCD panel on the J18 connector.

Example (enable SPI bus):
```
SYS:SPI 1
```

#### SYStem:SPI?
Return status of SPI bus.

Status|Description
------|-----------
1|Enabled
0|Disabled

Example:
```
SYS:SPI?
0
```

### SSH Server Commands

#### SYStem:SSH:SERVer
Control whether SSH server is enabled or not.
After making change configuration needs to be saved and unit reset.

Default: OFF

Example:
```
SYS:SSH:SERV ON
```

#### SYStem:SSH:SERVer?
Display whether SSH server status.

Example:
```
SYS:SSH:SERV?
OFF
```

#### SYStem:SSH:AUTH
Toggle SSH server authentication mode. When enabled then SSH server will
require user to authenticate (password or publickey authentication).
When off, no authentication is needed.

Default: ON

Example:
```
SYS:SSH:AUTH OFF
```

#### SYStem:SSH:AUTH?
Display whether SSH server authentication is enabled or not.

Example:
```
SYS:SSH:AUTH?
ON
```

#### SYStem:SSH:PORT
Set TCP port where SSH server will listen on.
If this setting is not set then default port will be used.

Default: 22 (default SSH port)

Example:
```
SYS:SSH:PORT 8022
```

#### SYStem:SSH:PORT?
Display currently configured port for SSH server.

(if port is set to 0, then default Telnet port will be used)

Example:
```
SYS:SSH:PORT?
8022
```

#### SYStem:SSH:USER
Configure username that is allowed to login to this server using SSH.

When no username is set, password authentication is disabled.

Default: <none>

Example (set username):
```
SYS:SSH:USER admin
```

Example (remove username):
```
SYS:SSH:USER
```

#### SYStem:SSH:USER?
Display currently configured SSH user (login) name.

When no username is set, password authentication is disabled.

Example:
```
SYS:SSH:USER?
admin
```

#### SYStem:SSH:PASSword
Configure password for the SSH user. Password is hashed using SHA-512 Crypt algorithm.

Default: <none>

Example (set passwod):
```
SYS:SSH:PASS mypassword
```

Example (remove password):
```
SYS:SSH:PASS
```

#### SYStem:SSH:PASSword?
Display currently configured SSH user password hash.

When no password is set, password authentication is disabled.

Example:
```
SYS:SSH:PASS?
$6$QvD5AkWSuydeH/EB$UsYA0cymsCRSse78fN4bMb5q0hM5B7YUNSFd3zJfMDbTG7DOH8iuMufVjsvqBOxR9YCJYSHno4CFeOhLtTGLx.
```

#### SYStem:SSH:KEY?
Display list of server private keys. Currently there is no support to
extract/export private keys. This command only displays SHA256 checksums for
each key.

Example:
```
SYS:SSH:KEY?
ecdsa                     121 SHA256:bDd9a2FrWRCyGxwgNZzzejEh+0ivXkww6nbM+4cIfSg
ed25519                    82 SHA256:/si832zNTkrxn0MHh8dhwfa6KlDAPcTRHsoqZbeVaSM
```

#### SYStem:SSH:KEY:CREate
Create SSH Server Private Key. Generated key is saved on the filesystem (littlefs) and
is used by the SSH server as its server private key.

Command takes key type as parameter.

Currently supported key types:

 - ECDSA
 - ED25519
 - ALL (create all supported keys)

Example:
```
SYS:SSH:KEY:CREATE ED25519
Generating ed25519 private key...
OK
```

#### SYStem:SSH:KEY:DELete
Delete SSH Server Private key. Key is deleted from the internal filesystem (littlefs).
When rotating server keys, old key must be first removed, before new one can be created.

Command takes key type as parameter.

Example:
```
SYS:SSH:KEY:DEL ECDSA
Deleting ecdsa private key...
Private key deleted.
```

#### SYStem:SSH:KEY:LIST?
Display list of server private keys.
This is same as command SYS:SSH:KEY?

#### SYStem:SSH:PUBKEY?
Display list of user name and public key pairs that can be used to login
using publicky authentication.

Example:
```
SYS:SSH:PUBKEY?
1: admin ssh-ed25519 AAAAC3NzaC1lZDI1NTE5AAAAIOOWu9+yEevReQUXEDgEMAIrs1DERTwZeSRRhIqioC6x admin@ws1
2: testuser ecdsa-sha2-nistp256 AAAAE2VjZHNhLXNoYTItbmlzdHAyNTYAAAAIbmlzdHAyNTYAAABBBH+E8WDRmrU2fKizKDyQXdLj3YGh7w5Wl7F2clpzHvGWIoBAJ/nsyUpMCqujzG7eD0EOKukBcb6vqyf2IQ96GLU= testuser@localhost
```

#### SYStem:SSH:PUBKEY:ADD
Add SSH public key for user to authenticate with.
Command takes two parameters "username", and "public key" (in OpenSSH format).
Currently up to 4 pubic keys can be added.

Parameters: <username> <ssh publickey>

Example:
```
SYS:SSH:PUBKEY ADD amdin ssh-ed25519 AAAAC3NzaC1lZDI1NTE5AAAAIOOWu9+yEevReQUXEDgEMAIrs1DERTwZeSRRhIqioC6x admin@ws1
SSH Public key added: slot 1: ssh-ed25519 (admin)
```

#### SYStem:SSH:PUBKEY:DELete
Delete SSH Public key.

Parameters: <key number>

(Command SYS:SSH:PUBKEY? can be used to find out key numbers.)

Example:
```
SYS:SSH:PUBKEY:DEL 1
SSH Public key deleted: slot 1: admin:ssh-ed25519 (admin@ws1)
```

#### SYStem:SSH:PUBKEY:LIST?
Display list of user name and public key pairs that can be used to login
This is same as SYS:SSH:PUBKEY?

### Telnet Server Commands

#### SYStem:TELNET:SERVer
Control whether Telnet server is enabled or not.
After making change configuration needs to be saved and unit reset.

Default: OFF

Example:
```
SYS:TELNET:SERV ON
```

#### SYStem:TELNET:SERVer?
Display whether Telnet server status.

Example:
```
SYS:TELNET:SERV?
OFF
```

#### SYStem:TELNET:AUTH
Toggle Telnet server authentication mode. When enabled then Telnet server will
prompt user for login/password. When off, no authentication is needed.

Default: ON

Example:
```
SYS:TELNET:AUTH OFF
```

#### SYStem:TELNET:AUTH?
Display whether Telnet server authentication is enabled or not.

Example:
```
SYS:TELNET:AUTH?
ON
```

#### SYStem:TELNET:PORT
Set TCP port where Telnet server will listen on.
If this setting is not set then default port will be used.

Default: 23 (default Telnet port)

Example:
```
SYS:TELNET:PORT 8000
```

#### SYStem:TELNET:PORT?
Display currently configured port for Telnet server.

(if port is set to 0, then default Telnet port will be used)

Example:
```
SYS:TELNET:PORT?
8000
```

#### SYStem:TELNET:RAWmode
Configure Telnet server mode. By default Telnet server uses Telnet protocol, but
setting this option causes Telnet protocol to be disabled. And server uses "raw TCP" mode.

Default: OFF

Example:
```
SYS:TELNET:RAW ON
```

#### SYStem:TELNET:RAWmode?
Display if "raw TCP" mode is enabled or not.

Example:
```
SYS:TELNET:RAW?
OFF
```

#### SYStem:TELNET:USER
Configure username that is allowed to login to this server using Telnet.

Default: <none>

Example:
```
SYS:TELNET:USER admin
```

#### SYStem:TELNET:USER?
Display currently configured telnet user (login) name.

Example:
```
SYS:TELNET:USER?
admin
```

#### SYStem:TELNET:PASSword
Configure password for the telnet user. Password is hashed using SHA-512 Crypt algorithm.

Default: <none>

Example:
```
SYS:TELNET:PASS mypassword
```

#### SYStem:TELNET:PASSword?
Display currently configured telnet user password hash.

Example:
```
SYS:TELNET:PASS?
$6$QvD5AkWSuydeH/EB$UsYA0cymsCRSse78fN4bMb5q0hM5B7YUNSFd3zJfMDbTG7DOH8iuMufVjsvqBOxR9YCJYSHno4CFeOhLtTGLx.
```

#### SYStem:TIME
Set system Real-Time Clock (RTC) time.

This command expects time in following format:
  YYYY-MM-DD HH:MM:SS

Example:
```
SYS:TIME 2022-09-19 18:55:42
```

#### SYStem:TIME?
Return current Real-Time Clock (RTC) time.
This is only available if using Pico W and it has successfully
gotten time from a NTP server or RTC has been initialized using
SYStem:TIME command.

Command returns nothing if RTC has not been initialized.

Example:
```
SYS:TIME?
2022-09-19 18:55:42
```

#### SYStem:TIMEZONE
Set POSIX timezone to use when getting time from a NTP server.
If DHCP server does not supply POSIX Timezone (DHCP Option 100), then this
command can be used to specify local timezone.

This command takes POSIX timezone string as argument (or if argument is blank,
then it clears existinh timezone setting).

Example (set Pacific Standard time as local timezone):
```
SYS:TIMEZONE PST8PDT7,M3.2.0/2,M11.1.0/02:00:00
```

Example (clear timezone setting):
```
SYS:TIMEZONE
```

#### SYStem:TIMEZONE?
Return current POSIX timezone setting.

Command returns nothing if no timezone has been set.

Example:
```
SYS:TIMEZONE?
PST8PDT7,M3.2.0/2,M11.1.0/02:00:00
```

#### SYStem:TLS:CERT
Upload or delete TLS certificate for the HTTP server.
Note, both certificate and private key must be installed before HTTPS server will
activate (when system is restarted next time).

When run without arguments this will prompt to paste TLS (X.509) certificate
in PEM format.  When run with "DELETE" argument currently installed certificate
will be deleted.

Example (upload/paste certificate):
```
SYS:TLS:CERT
Paste certificate in PEM format:

```

Example (delete existing certificate from flash memory):
```
SYS:TLS:CERT DELETE
```

#### SYStem:TLS:CERT?
Display currently installed certificate.

Example:
```
SYS:TLS:CERT?
```

#### SYStem:TLS:PKEY
Upload or delete (TLS Certificate) Private key for the HTTP server.
Note, both certificate and private key must be installed before HTTPS server will
activate (when system is restarted next time).

When run without arguments this will prompt to paste private key
in PEM format.  When run with "DELETE" argument currently installed private key
will be deleted.

Example (upload/paste private key):
```
SYS:TLS:PKEY
Paste private key in PEM format:

```

Example (delete existing private key from flash memory):
```
SYS:TLS:PKEY DELETE
```

#### SYStem:TLS:PKEY?
Display currently installed private key.

Example:
```
SYS:TLS:CERT?
```

#### SYStem:UPTIme?
Return time elapsed since unit was last rebooted.

Example:
```
SYS:UPTIME?
up 4 days, 22 hours, 27 minutes
```

#### SYStem:UPGRADE
Reboot unit to USB (BOOTSEL) mode for firmware upgrade.
This command triggers fanpico to reboot and enter USB "mode", where
new firmware can simply be copied to the USB drive that appears.
After file has been copied, fanpico will automatically reboot to new
firmware image.

Example:
```
SYS:VER?
```

#### SYStem:VERsion?
Display software version and copyright information.

Example:
```
SYS:VER?
```

#### SYStem:VSENSORS?
Display number of virtual (temperature) sensors available.

Example:
```
SYS:VSENSORS?
8
```

#### SYStem:WIFI?
Check if the unit support WiFi networking.
This should be used to determine if any other "WIFI"
commands will be available.

Return values:

0 = No WiFi support (Pico).
1 = WiFi supported (Pico W).

Example:
```
SYS:WIFI?
1
```

#### SYStem:WIFI:AUTHmode
Set Wi-Fi Authentication mode.

Following modes are currently supported:

Mode|Description|Notes
----|-----------|-----
default|Use system default|Currently default is WPA2
WPA3_WPA2|Use WPA3/WPA2 (mixed) mode|
WPA3|Use WPA3 only|
WPA2|Use WPA2 only|
WPA2_WPA|Use WPA2/WPA (mixed) mode|
WPA|Use WPA only|
OPEN|Use "Open" mode|No authentication.

Example:
```
SYS:WIFI:AUTH WPA3_WPA2
```

#### SYStem:WIFI:AUTHmode?
Return currently configured Authentication mode for the WiFi interface.

Example:

```
SYS:WIFI:AUTH?
default
```

#### SYStem:WIFI:COUntry
Set Wi-Fi Country code. By default, the country setting for the wireless adapter is unset.
This means driver will use default world-wide safe setting, which can mean that some channels
are unavailable.

Country codes are two letter (ISO 3166) codes. For example, Finland = FI, Great Britain = GB,
United States of Americ = US, ...

Example:
```
SYS:WIFI:COUNTRY US
```

#### SYStem:WIFI:COUntry?
Return currently configured country code for the Wi-Fi interface.

Codes used are the ISO 3166 standard two letter codes ('XX' means unset/worldwide setting).

Example:

```
SYS:WIFI:COUNTRY?
US
```

#### SYStem:WIFI:HOSTname
Set system hostname. This will be used with DHCP and SYSLOG.
If hostname is not defined then system will default to generating
hostname as follows:
  BrickPico-xxxxxxxxxxxxxxxx

(where "xxxxxxxxxxxxxxxx" is the BrickPico serial number)

Example:
```
SYS:WIFI:HOSTNAME fanpico1
```

#### SYStem:WIFI:HOSTname?
Return currently configured system hostname.

Example:

```
SYS:WIFI:HOSTNAME?
fanpico1
```

#### SYStem:WIFI:IPaddress
Set staticlly configured IP address.

Set address to "0.0.0.0" to enable DHCP.

Example:

```
SYS:WIFI:IP 192.168.1.42
```

#### SYStem:WIFI:IPaddress?
Display currently configured (static) IP address.
If no static address is configured, DHCP will be used.

Set address to "0.0.0.0" to enable DHCP.

Example:

```
SYS:WIFI:IP?
0.0.0.0
```

#### SYStem:WIFI:MODE
Set WiFi connection mode. Normally this setting is not needed with modern APs.

However, if FanPico is failing to connect to WiFi network, this couldbe
due to old firmware on the AP (upgrading to latest firmware typically helps).
If firmware update did not help or there is no updated firmware available, setting
connection mode to synchronous can help (however this could cause FanPico to "hang" for up to 60 seconds
during boot up).

Mode|Description
------|-----------
0|Asynchronous connection mode (default)
1|Synchronous connection mode

Default: 0

Example:

```
SYS:WIFI:MODE 1
```

#### SYStem:WIFI:MODE?
Display currently configured WiFi connection mode?

Example:

```
SYS:WIFI:MODE?
0

```

#### SYStem:WIFI:NETMASK
Set statically configured netmask.

Example:

```
SYS:WIFI:NETMASK 255.255.255.0
```

#### SYStem:WIFI:NETMASK?
Display currently configured (static) netmask.

Example:

```
SYS:WIFI:NETMASK?
255.255.255.0
```

#### SYStem:WIFI:GATEWAY
Set statically configured default gateway (router).

Example:

```
SYS:WIFI:GATEWAY 192.168.1.1
```

#### SYStem:WIFI:GATEWAY?
Display currently configured default gateway (router).

Example:

```
SYS:WIFI:GATEWAY?
192.168.1.1
```

#### SYStem:WIFI:NTP
Configure IP for NTP server to use.

Set to "0.0.0.0" to use server provided by DHCP.

Example:

```
SYS:WIFI:NTP 192.168.1.10
```

#### SYStem:WIFI:NTP?
Display currently configure NTP server.

Note, "0.0.0.0" means to use DHCP.

Example:

```
SYS:WIFI:NTP?
192.168.1.10
```

#### SYStem:WIFI:SYSLOG
Configure IP for Syslog server to use.

Set to "0.0.0.0" to use server provided by DHCP.

Example:

```
SYS:WIFI:SYSLOG 192.168.1.20
```

#### SYStem:WIFI:SYSLOG?
Display currently configured Syslog server.

Note, "0.0.0.0" means to use DHCP.

Example:

```
SYS:WIFI:SYSLOG?
192.168.1.20
```

#### SYStem:WIFI:MAC?
Display WiFi adapter MAC (Ethernet) address.

Example:

```
SYS:WIFI:MAC?
28:cd:c1:01:02:03
```

#### SYStem:WIFI:SSID
Set Wi-Fi network SSID. FanPico will automatically try joining to this network.

Example
```
SYS:WIFI:SSID mynetwork
```

#### SYStem:WIFI:SSID?
Display currently configured Wi-Fi network SSID.

Example:

```
SYS:WIFI:SSID?
mynetwork
```

#### SYStem:WIFI:STATus?
Display WiFi Link status.

Return value: linkstatus,current_ip,current_netmask,current_gateway

Link Status:

Value|Description
-----|-----------
0    |Link is down.
1    |Connected to WiFi.
2    |Connected to WiFi, but no IP address.
3    |Connected to WiFi with and IP address.
-1   |Connection failed.
-2   |No matching SSID found(could be out of range, or down).
-3   |Authentication failed (wrong password?)

Example:

```
SYS:WIFI:STAT?
1,192.168.1.42,255.255.255.0,192.168.1.1
```

#### SYStem:WIFI:STATS?
Display TCP/IP stack (LwIP) statistics.

NOTE, this command only works on "Debug" builds of the firmware currently.

Example
```
SYS:WIFI:STATS?
```

#### SYStem:WIFI:PASSword
Set Wi-Fi (PSK) password/passrase.

Example
```
SYS:WIFI:PASS mynetworkpassword
```

#### SYStem:WIFI:PASSword?
Display currently configured Wi-Fi (PSK) password/passphrase.

Example:

```
SYS:WIFI:PASS?
mynetworkpassword
```

### WRIte Commands

These commands are for turning output ports ON/OFF and for adjusting output PWM duty cycle.

#### WRIte:OUTPUTx

Turn output on or off.

Example: Turn OUTPUT1 on.
```
WRITE:OUTPUT1 ON
```

Example: Turn OUTPUT1 off.
```
WRITE:OUTPUT1 OFF
```

#### WRIte:OUTPUTx:PWM

Set output PWM duty cycle. Valid values are from 0 to 100.

Example: Set OUTPUT2 to 25% duty cycle.
```
WRITE:OUTPUT2:PWM 25
```

#### WRIte:OUTPUTx:STAte

Turn output  on or off. This is same as WRIte:OUTPUTx command.

Example: Turn OUTPUT1 on.
```
WRITE:OUTPUT1:STATE ON
```

Example: Turn OUTPUT1 off.
```
WRITE:OUTPUT1:STATE OFF
```

#### WRIte:VSENSORx

Set/update temperature of a virtual sensor. This can be used by a program on the host
system to feed external temperature information into BrickPico.

Example: Set VSENSOR1 temperature to 42.1C
```
WRITE:VSENSOR1 42.1
```

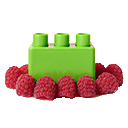
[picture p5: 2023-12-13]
src/httpd-fs/img/brickpico.png

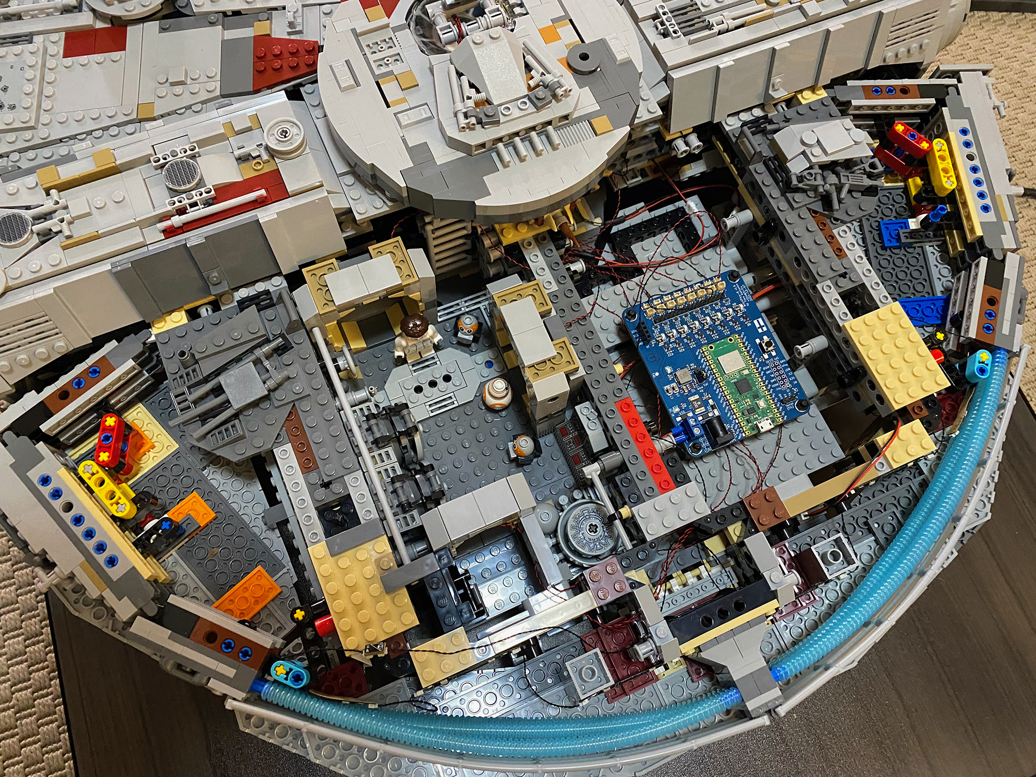
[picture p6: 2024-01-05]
images/falcon-back.jpg

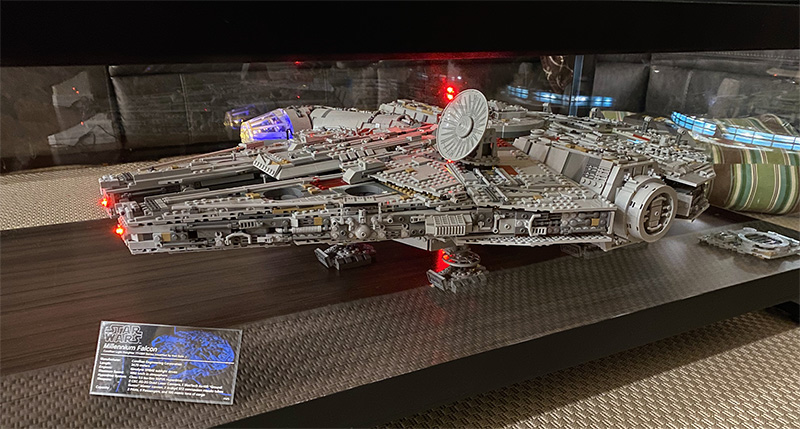
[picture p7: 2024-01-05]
images/falcon-lights-small.jpg

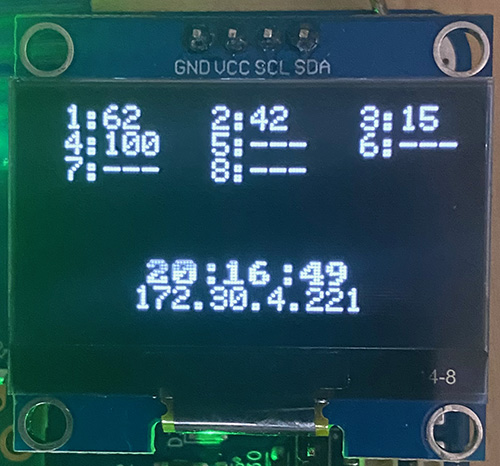
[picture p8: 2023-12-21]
images/oled-128x64-layout.jpg

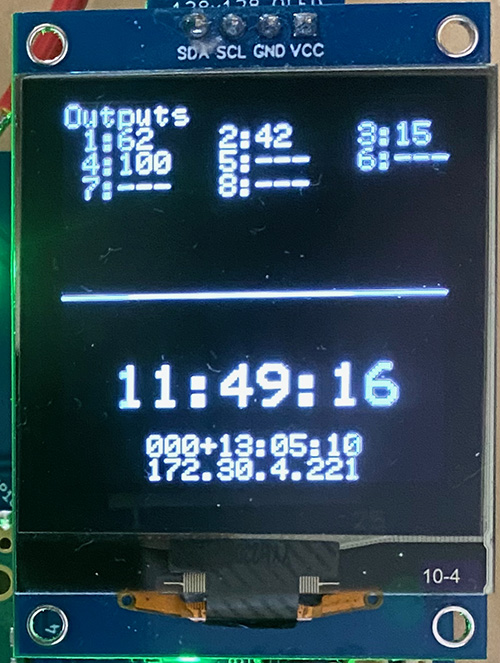
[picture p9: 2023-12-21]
images/oled-128x128-layout.jpg

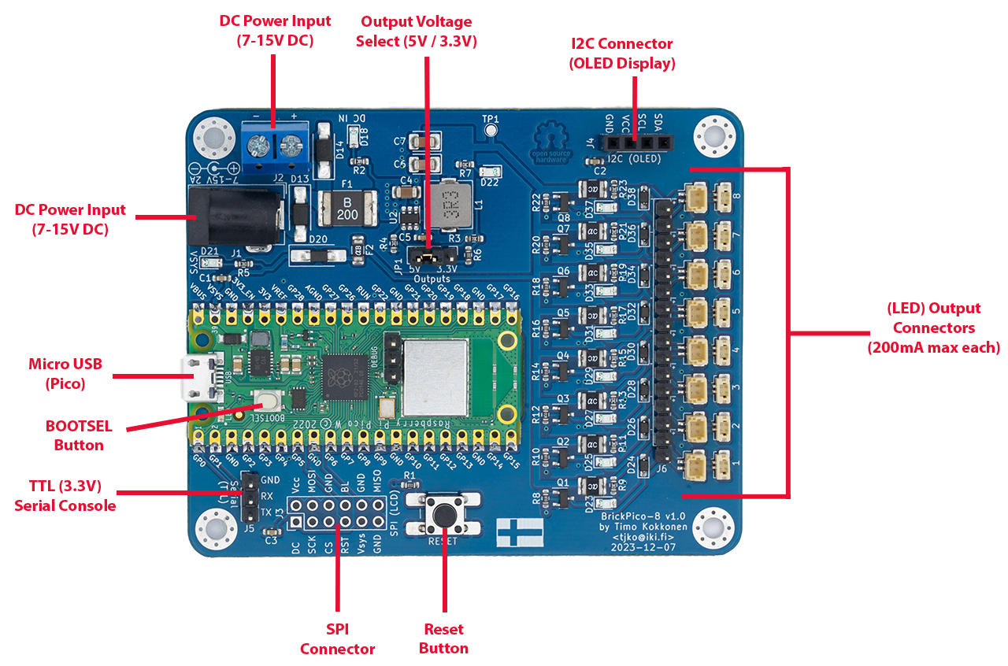
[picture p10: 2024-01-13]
images/brickpico-08-diagram.png

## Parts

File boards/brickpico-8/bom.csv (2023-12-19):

Item | Qty | Reference(s) | Value | LibPart | Footprint | Datasheet | DNP | LCSC Part Number | Mouser Part Number
1 | 4 | C1, C2, C3, C5 | 0.1uF | Device:C | Capacitor_SMD:C_0603_1608Metric_Pad1.08x0.95mm_HandSolder | ~ |  | C1591 | 80-C0603C104Z3VAC
2 | 1 | C4 | 10uF 50V | Device:C | Capacitor_SMD:C_1206_3216Metric_Pad1.33x1.80mm_HandSolder | ~ |  | C89632
3 | 2 | C6, C7 | 22uF 25V | Device:C_Polarized | Capacitor_Tantalum_SMD:CP_EIA-3528-21_Kemet-B_Pad1.50x2.35mm_HandSolder | ~ |  | C12891
4 | 13 | D1, D2, D3, D4, D5, D6, D8, D11, D12, D15, D16, D17, D19 | 3.3V | Device:D_TVS | Diode_SMD:D_SOD-323_HandSoldering | ~ |  | C78439 | 750-CPDV3V3A-HF
5 | 9 | D7, D24, D26, D28, D30, D32, D34, D36, D38 | 5V | Device:D_TVS | Diode_SMD:D_SOD-323_HandSoldering | ~ |  | C5180216 | 621-DESD5V0U1BA-7
6 | 2 | D9, D10 | 15V | Device:D_TVS | Diode_SMD:D_SOD-323_HandSoldering | ~ |  | C5199169
7 | 2 | D13, D14 | SK54A-LTP | Device:D_Schottky | Diode_SMD:D_SMA_Handsoldering | ~ |  | C669016 | 833-SK54A-LTP
8 | 11 | D18, D21, D22, D23, D25, D27, D29, D31, D33, D35, D37 | LED | Device:LED | LED_SMD:LED_0805_2012Metric_Pad1.15x1.40mm_HandSolder | ~ |  | C434432 | 710-150080GS75000
9 | 1 | D20 | SM5819PL 1A | Device:D_Schottky | Diode_SMD:D_SMA_Handsoldering | ~ |  | C669023 | 833-SM5819PL-TP
10 | 1 | F1 | Polyfuse 2A | Device:Polyfuse_Small | Fuse:Fuse_2920_7451Metric_Pad2.10x5.45mm_HandSolder | ~ |  | C910843
11 | 1 | F2 | Polyfuse 350mA | Device:Polyfuse_Small | Fuse:Fuse_1206_3216Metric_Pad1.42x1.75mm_HandSolder | ~ |  | C70072
12 | 8 | F3, F4, F5, F6, F7, F8, F9, F10 | Polyfuse 200mA | Device:Polyfuse_Small | Fuse:Fuse_1210_3225Metric_Pad1.42x2.65mm_HandSolder | ~ |  | C70088 | 530-0ZCJ0020FF2E
13 | 4 | H1, H2, H3, H4 | MountingHole_Pad | Mechanical:MountingHole_Pad | MountingHole:MountingHole_3.2mm_M3_Pad_Via | ~ |  | N/A | N/A
14 | 1 | J1 | DC Connector | Connector:Barrel_Jack_Switch | Connector_BarrelJack:BarrelJack_Wuerth_6941xx301002 | ~ |  | C720558
15 | 1 | J2 | Terminal Block | Connector_Generic:Conn_01x02 | TerminalBlock:TerminalBlock_bornier-2_P5.08mm | ~ |  | C1509679
16 | 1 | J3 | SPI (LCD) | Connector_Generic:Conn_02x06_Odd_Even | Connector_PinHeader_2.54mm:PinHeader_2x06_P2.54mm_Vertical | ~ |  | C492423
17 | 1 | J4 | I2C (OLED) | Connector_Generic:Conn_01x04 | Connector_PinSocket_2.54mm:PinSocket_1x04_P2.54mm_Vertical | ~ |  | C2691448
18 | 1 | J5 | Serial (TTL) | Connector_Generic:Conn_01x03 | Connector_PinHeader_2.54mm:PinHeader_1x03_P2.54mm_Vertical | ~ |  | C124376
19 | 1 | J6 | Conn_01x16 | Connector_Generic:Conn_01x16 | Connector_PinHeader_2.54mm:PinHeader_1x16_P2.54mm_Vertical | ~ |  | C2894939
20 | 8 | J7, J8, J9, J10, J11, J12, J13, J14 | JST SUR | Connector_Generic:Conn_01x02 | Connector_JST:JST_SUR_BM02B-SURS-TF_1x02-1MP_P0.80mm_Vertical | ~ |  | C385130
21 | 8 | J15, J16, J17, J18, J19, J20, J21, J22 | JST SRS | Connector_Generic:Conn_01x02 | Connector_JST:JST_SH_BM02B-SRSS-TB_1x02-1MP_P1.00mm_Vertical | ~ |  | C160388
22 | 1 | JP1 | Conn_01x03 | Jumper:Jumper_3_Bridged12 | Connector_PinHeader_2.54mm:PinHeader_1x03_P2.54mm_Vertical | ~ |  | C124376
23 | 1 | L1 | 3.3uH | Device:L | FanPico:L_7.3x7.3_H3.5_HandSolder | ~ |  | C5189747
24 | 8 | Q1, Q2, Q3, Q4, Q5, Q6, Q7, Q8 | 2N7002K | Transistor_FET:2N7002K | Package_TO_SOT_SMD:SOT-23 | https://www.diodes.com/assets/Datasheets/ds30896.pdf |  | C414015 | 512-2N7002K
25 | 9 | R1, R8, R10, R12, R14, R16, R18, R20, R22 | 1K | Device:R | Resistor_SMD:R_0603_1608Metric_Pad0.98x0.95mm_HandSolder | ~ |  | C22548
26 | 1 | R2 | 49.9K | Device:R | Resistor_SMD:R_0603_1608Metric_Pad0.98x0.95mm_HandSolder | ~ |  | C114624
27 | 1 | R3 | 52.3K | Device:R | Resistor_SMD:R_0603_1608Metric_Pad0.98x0.95mm_HandSolder | ~ |  | C185323
28 | 11 | R4, R5, R7, R9, R11, R13, R15, R17, R19, R21, R23 | 10K | Device:R | Resistor_SMD:R_0603_1608Metric_Pad0.98x0.95mm_HandSolder | ~ |  | C98220
29 | 1 | R6 | 80K | Device:R | Resistor_SMD:R_0603_1608Metric_Pad0.98x0.95mm_HandSolder | ~ |  | C3014409
30 | 1 | SW1 | Reset | Switch:SW_Push | FanPico:SW_PUSH_6mm_SMD_2 | ~ |  | C221880
31 | 1 | TP1 | TestPoint | Connector:TestPoint | TestPoint:TestPoint_Pad_D1.5mm | ~ |  | N/A | N/A
32 | 1 | U1 | Pico | fanpico:Pico | FanPico:RPi_Pico_PicoW_SMD_TH |  |  |  | 358-SC0918
33 | 1 | U2 | AP62301WU | Regulator_Switching:AP62300TWU | FanPico:TSOT-26 | https://www.diodes.com/assets/Datasheets/AP62300_AP62301_AP62300T.pdf |  | C3194340 | 621-AP62301WU-7

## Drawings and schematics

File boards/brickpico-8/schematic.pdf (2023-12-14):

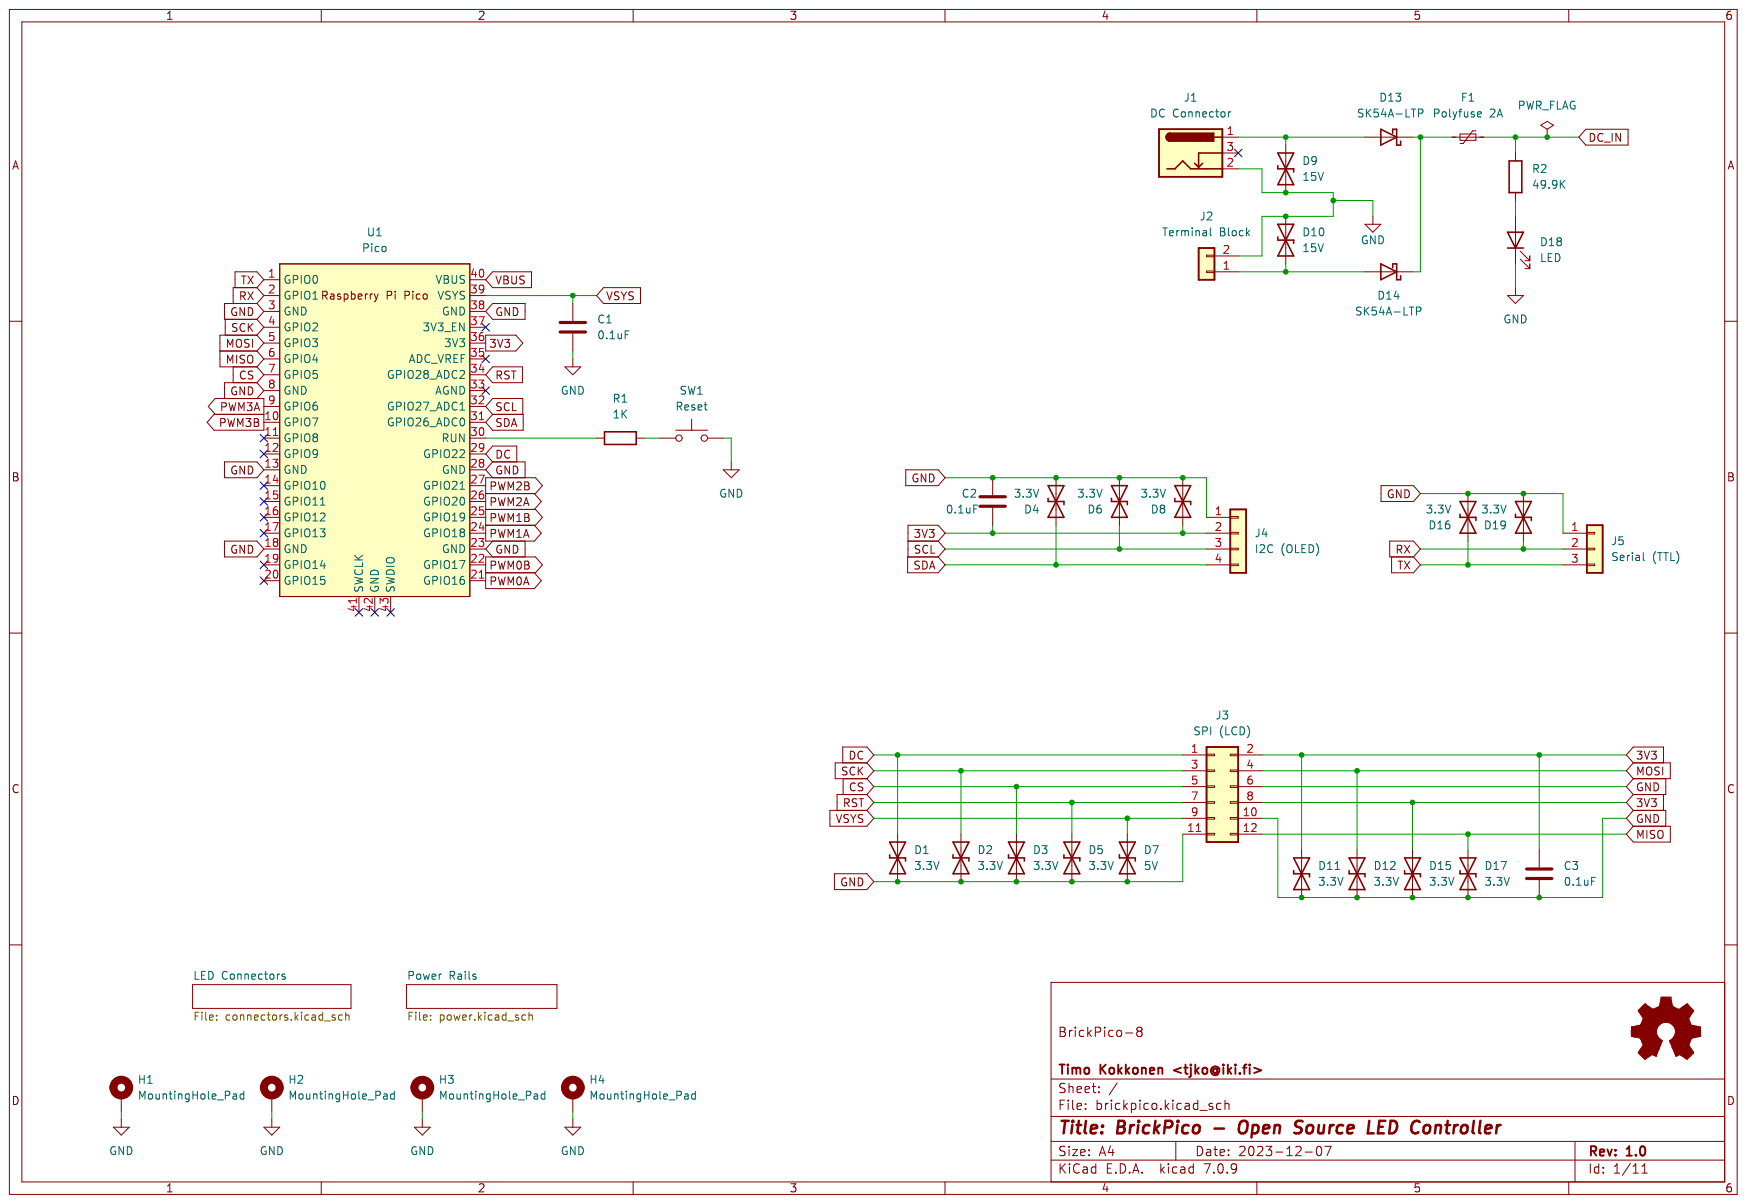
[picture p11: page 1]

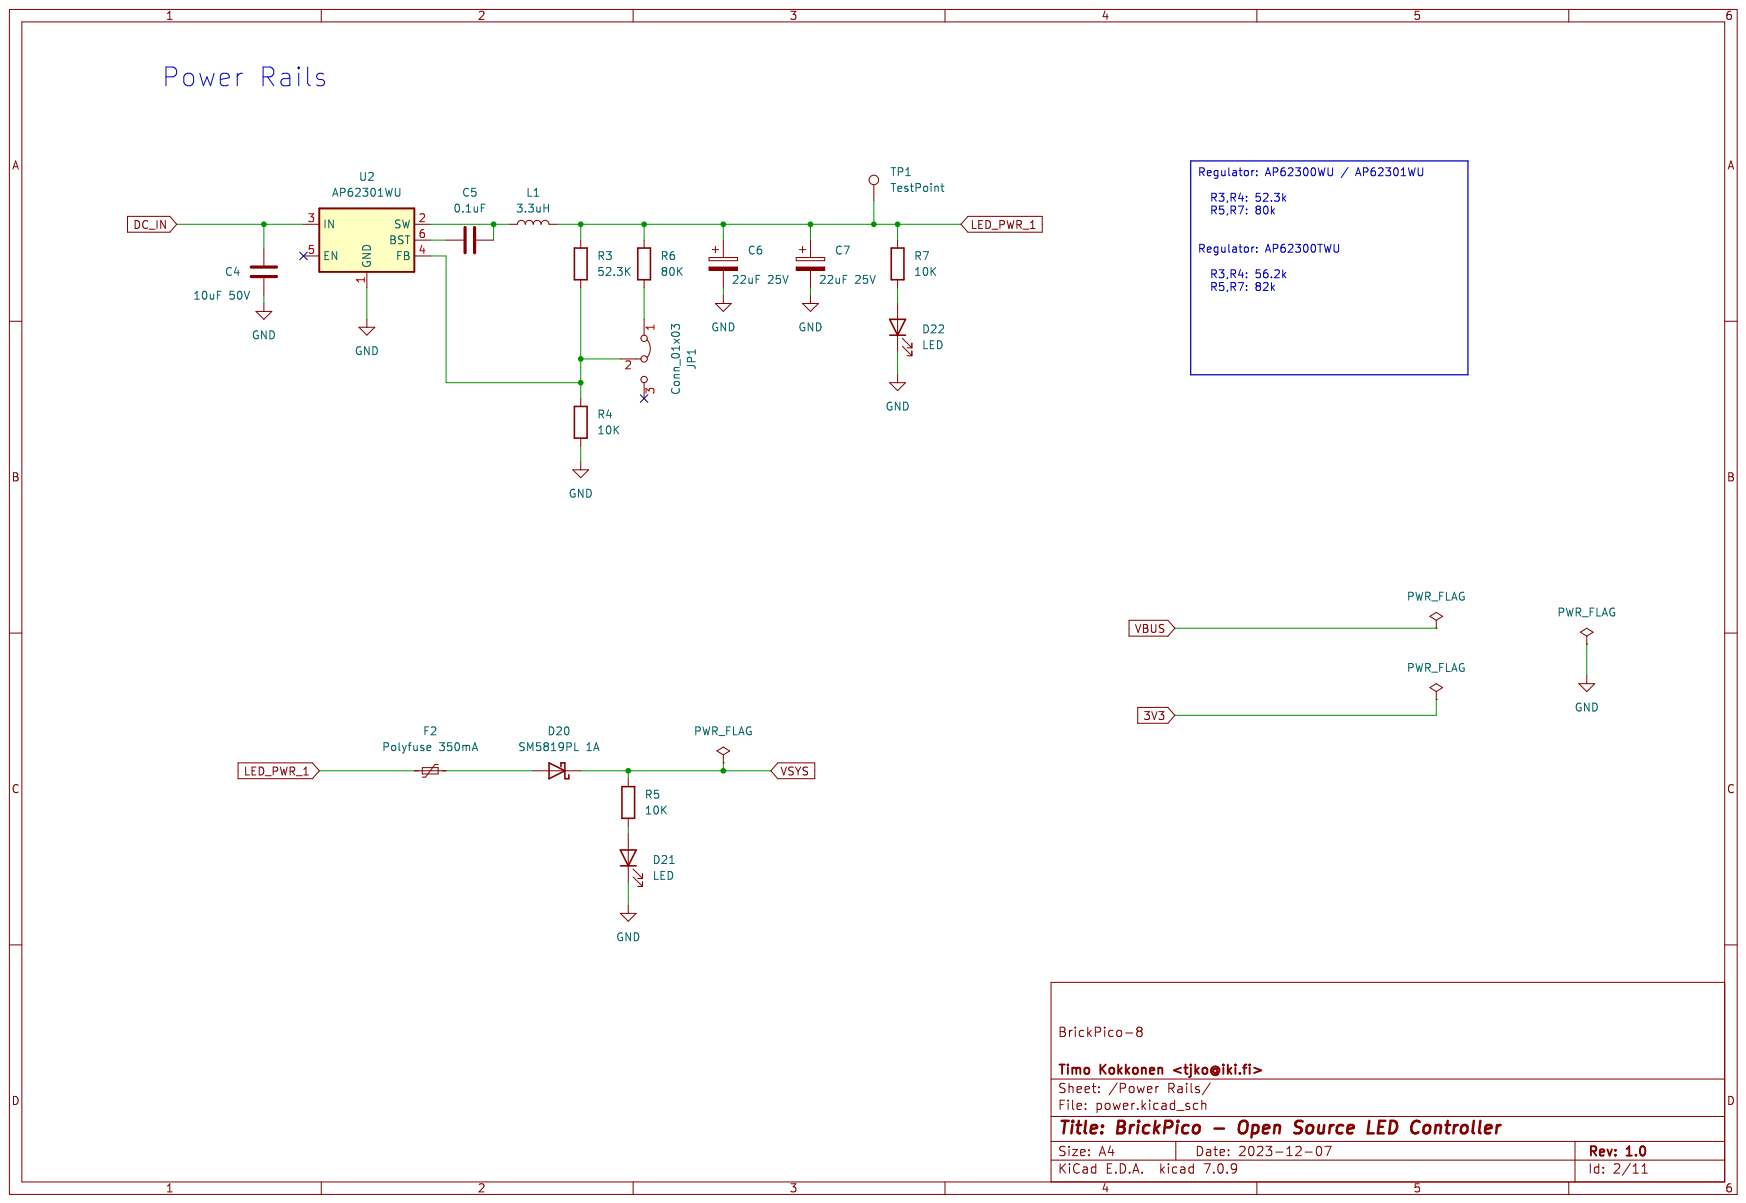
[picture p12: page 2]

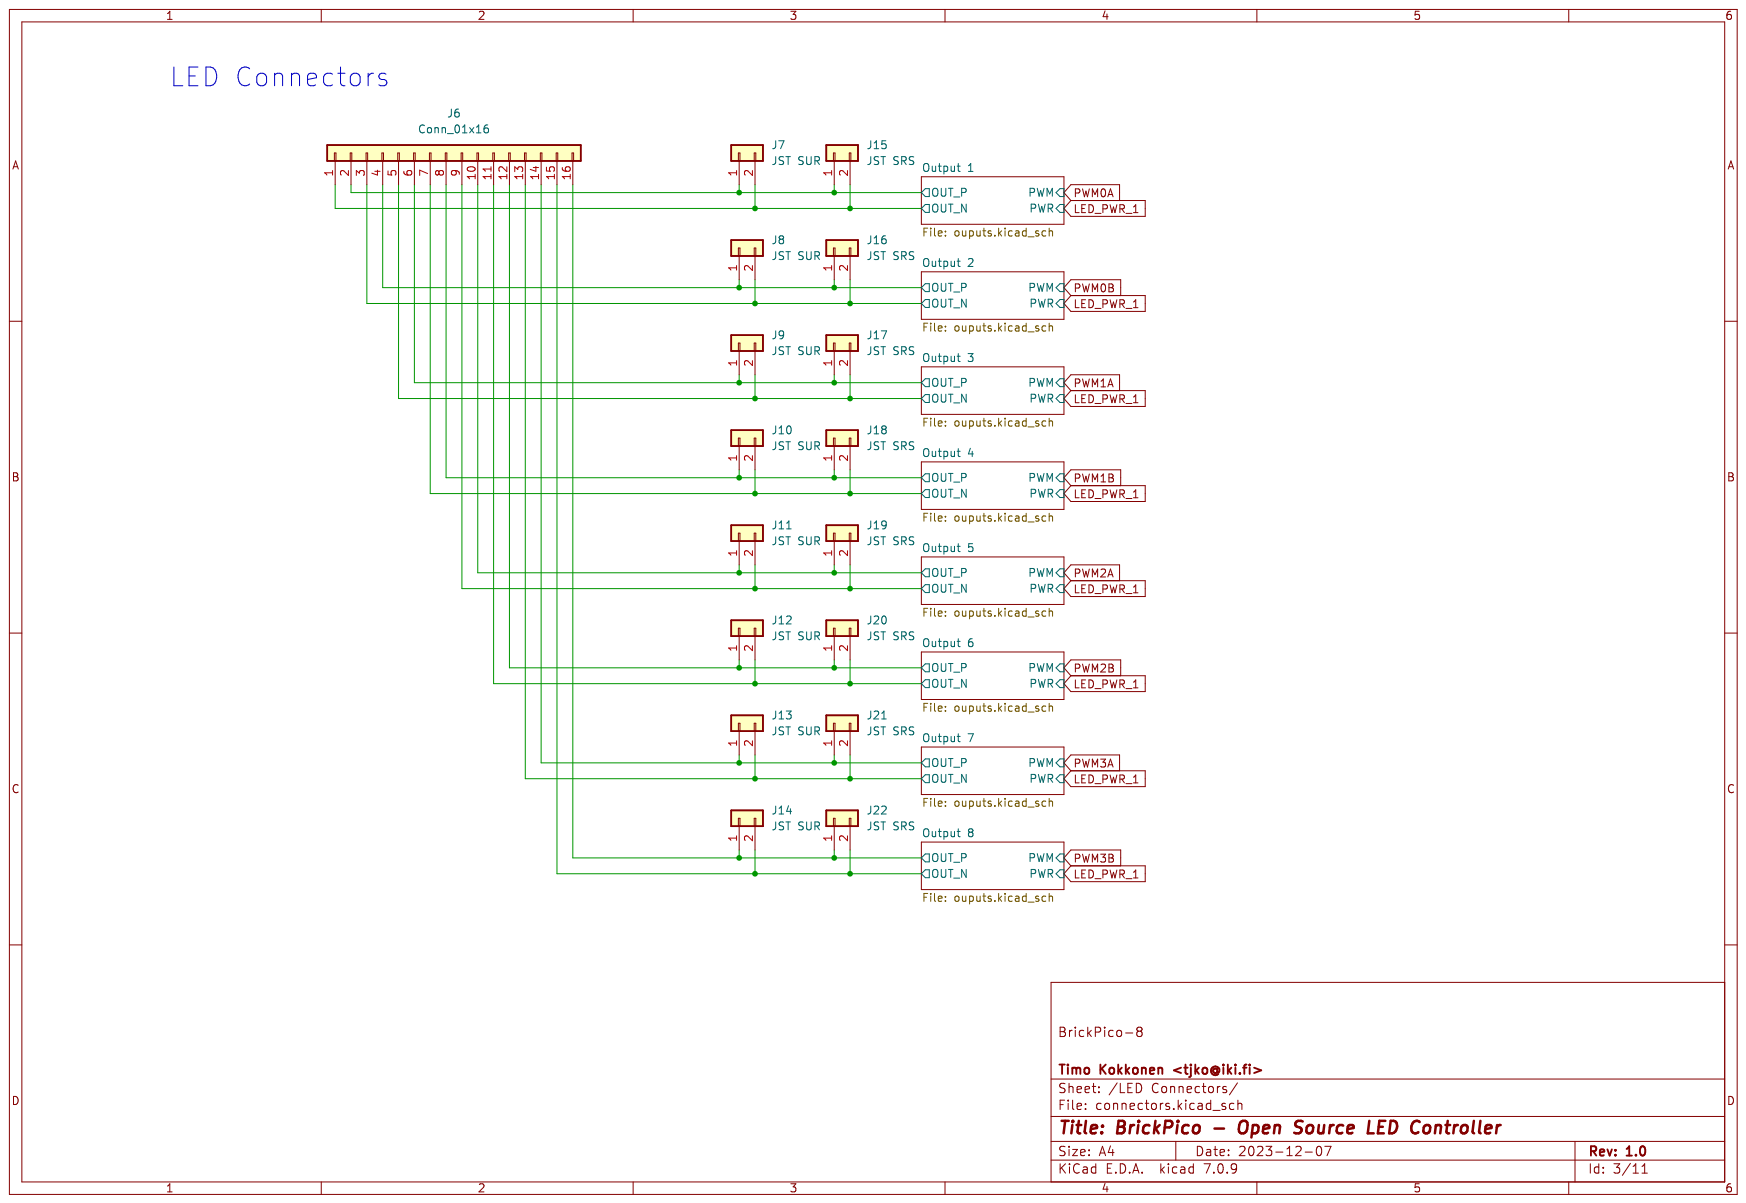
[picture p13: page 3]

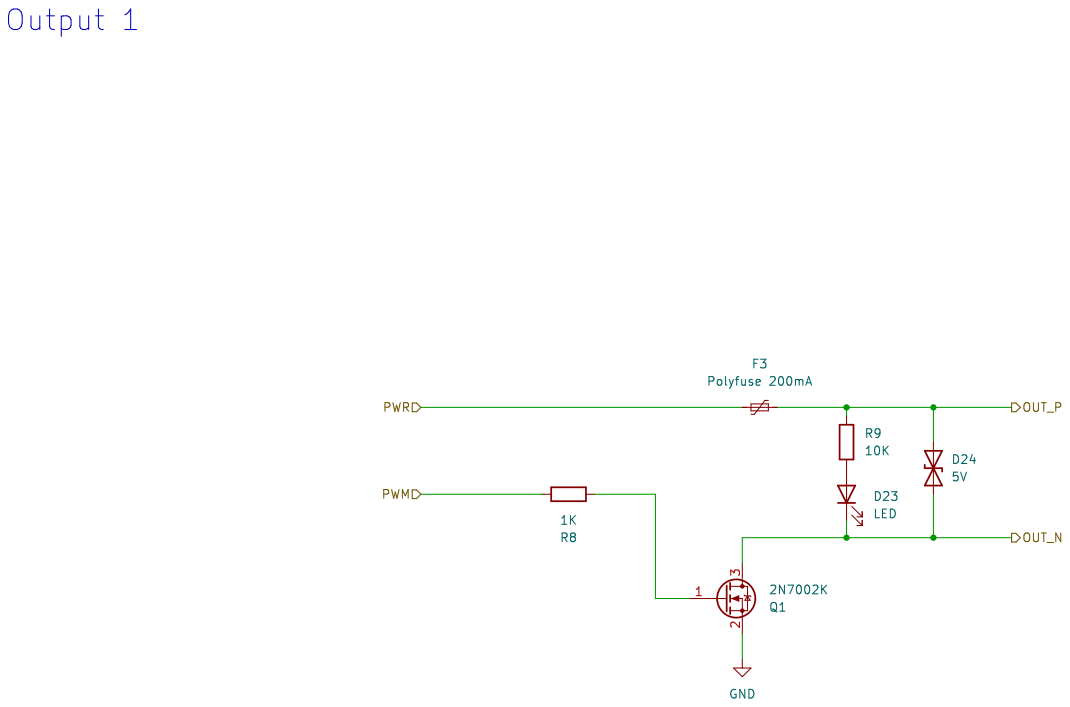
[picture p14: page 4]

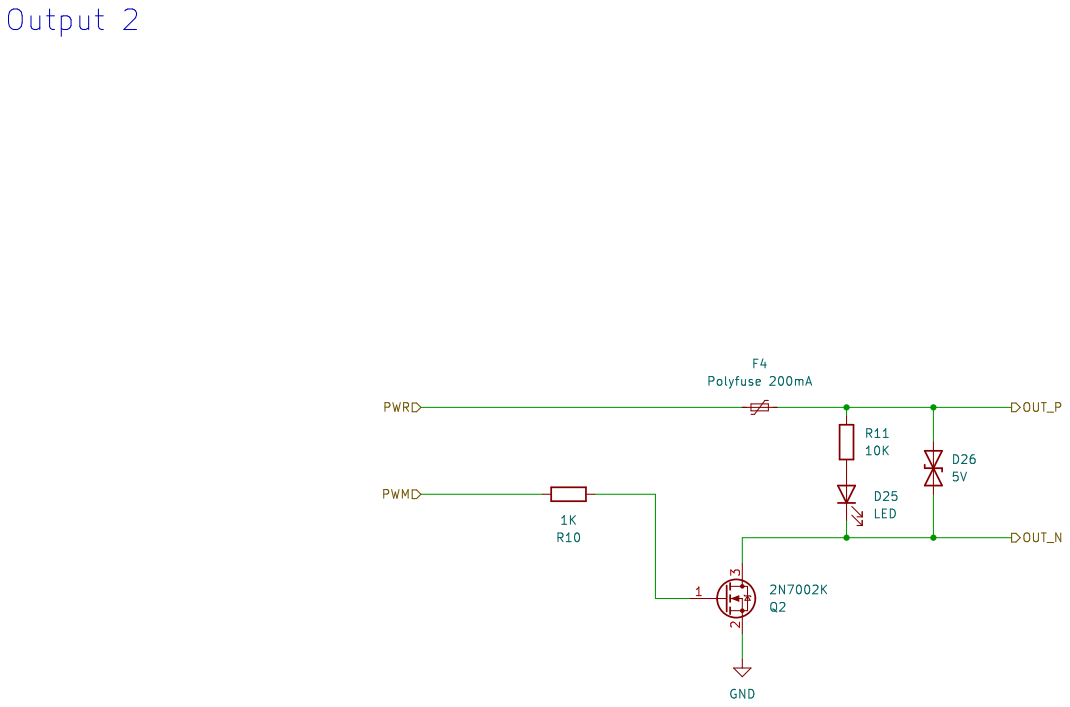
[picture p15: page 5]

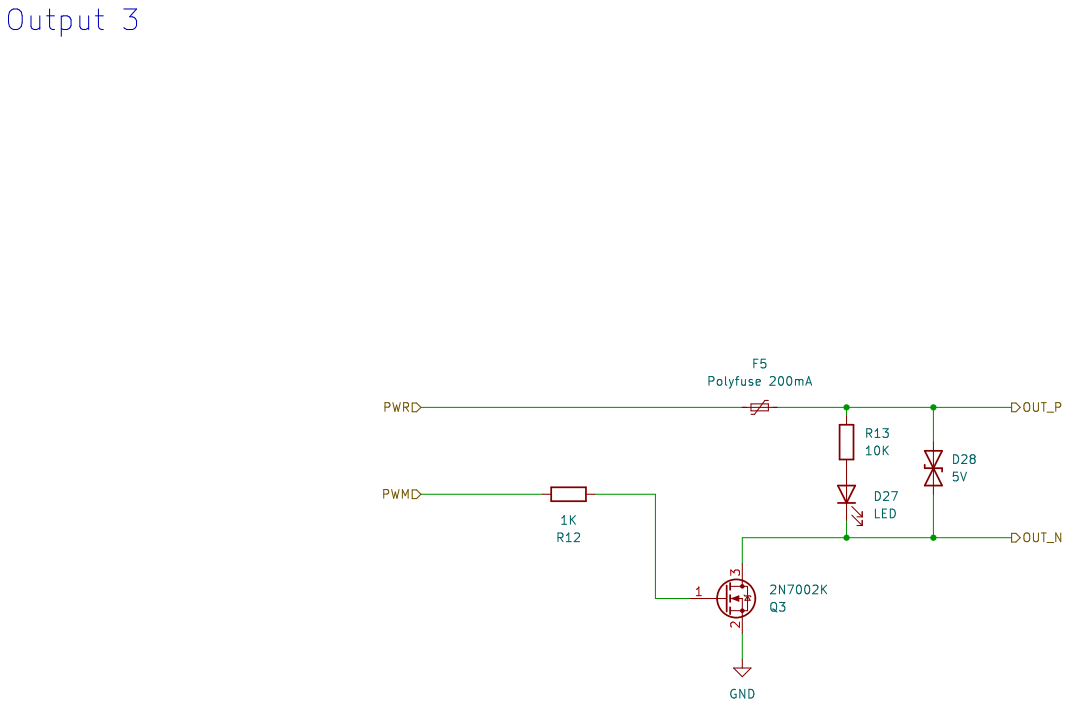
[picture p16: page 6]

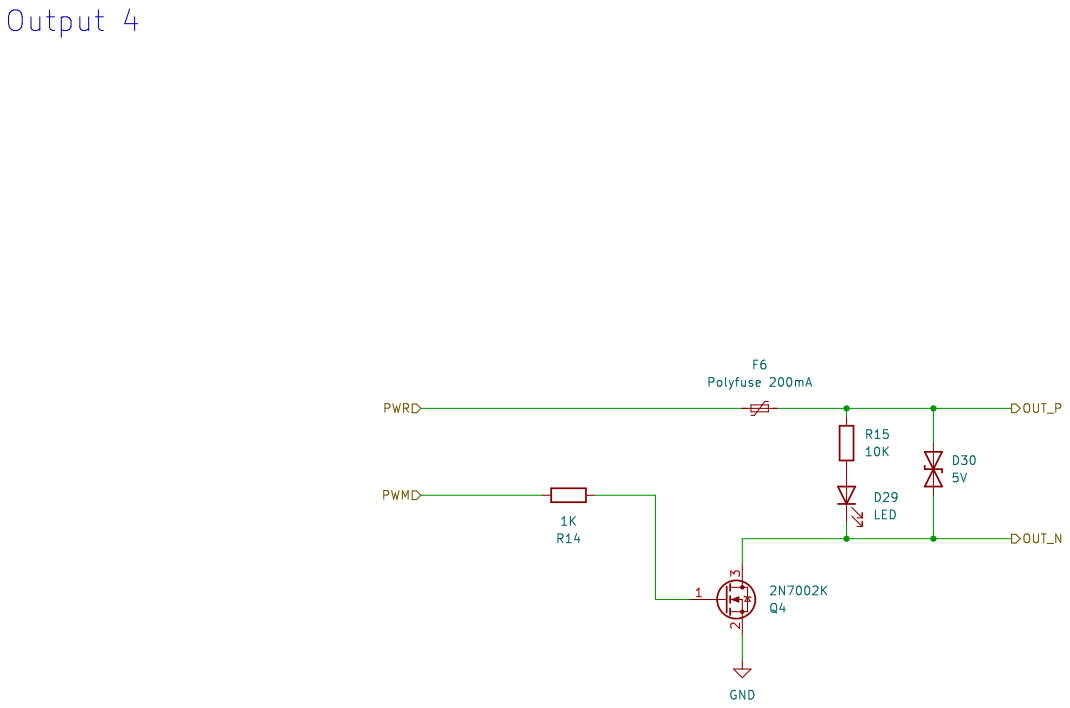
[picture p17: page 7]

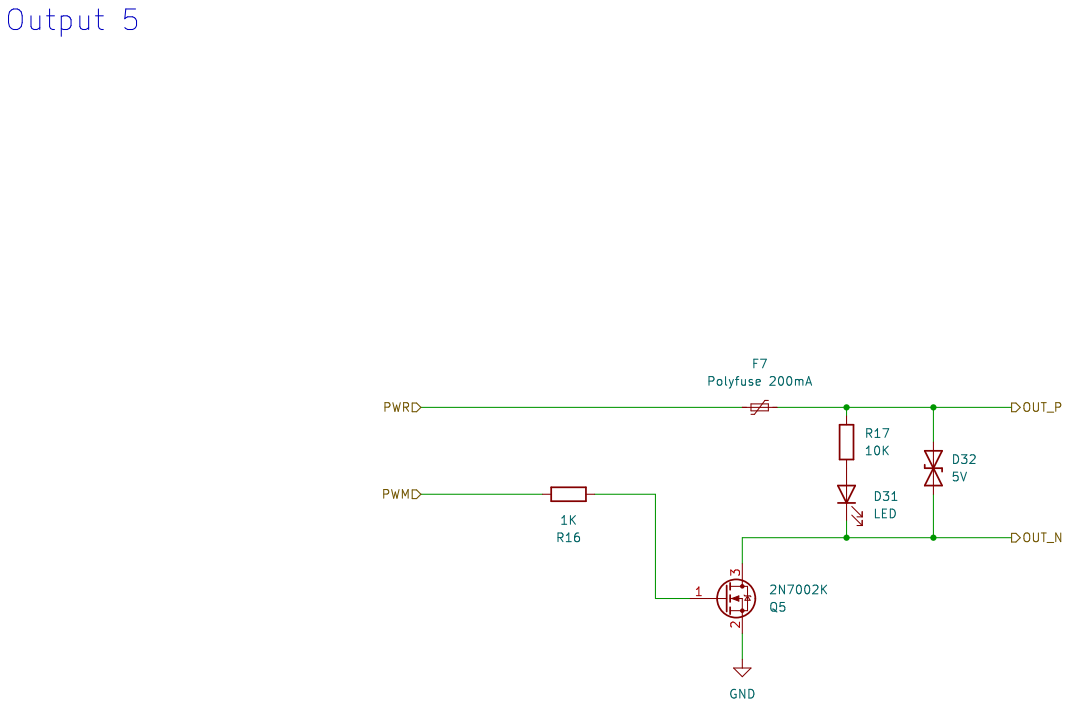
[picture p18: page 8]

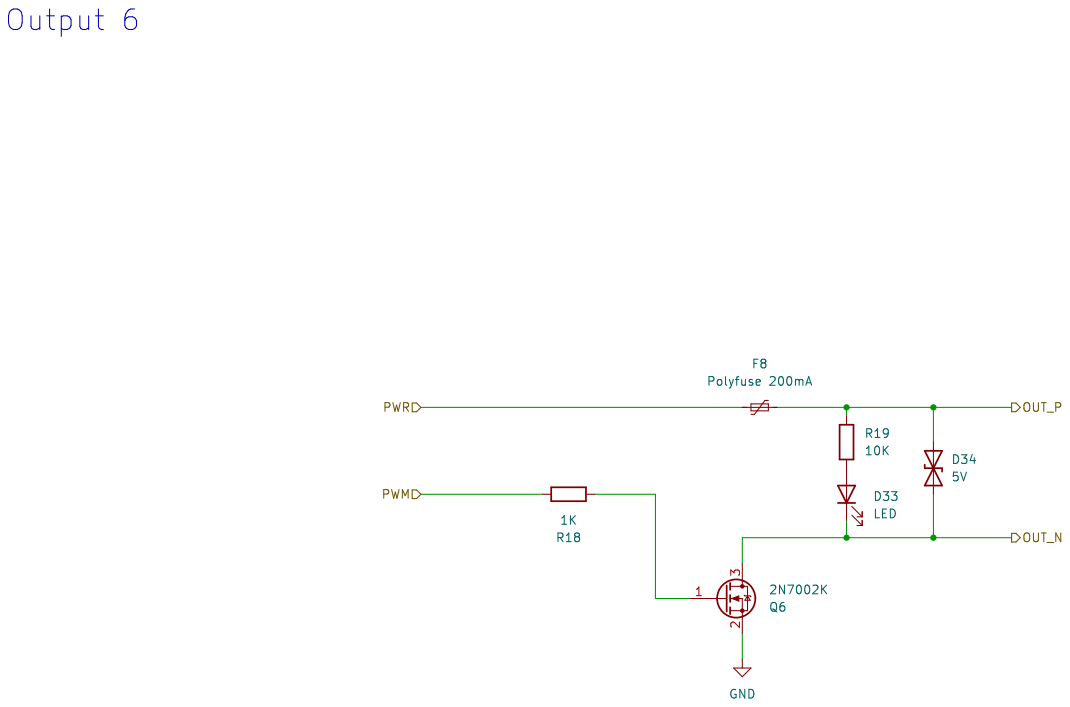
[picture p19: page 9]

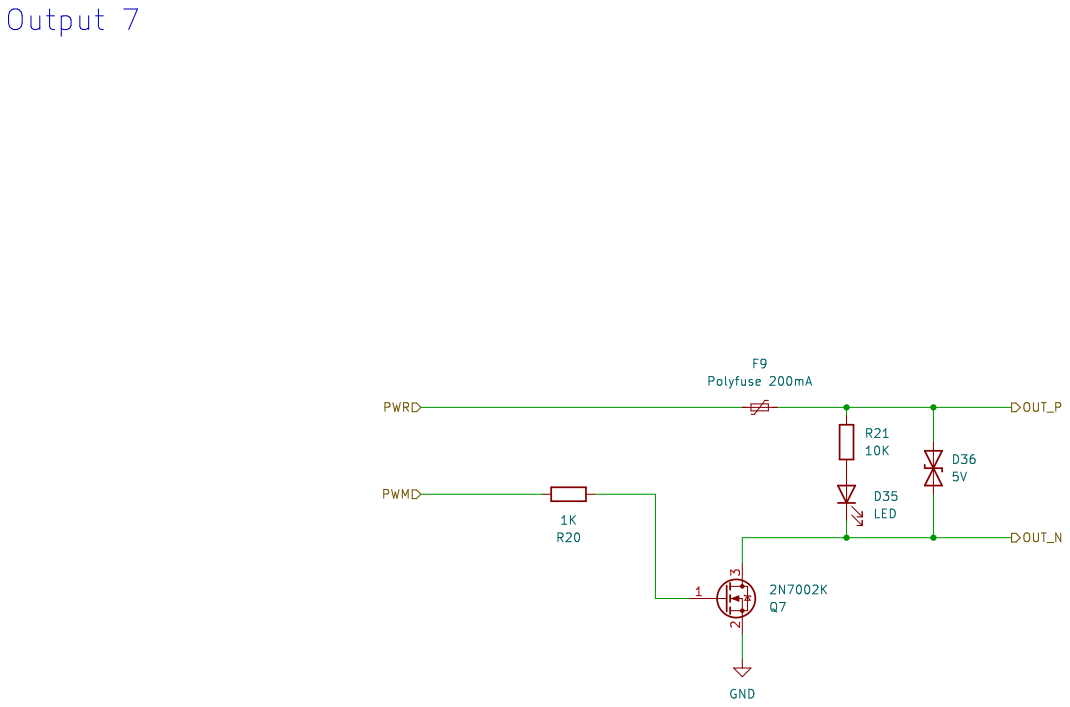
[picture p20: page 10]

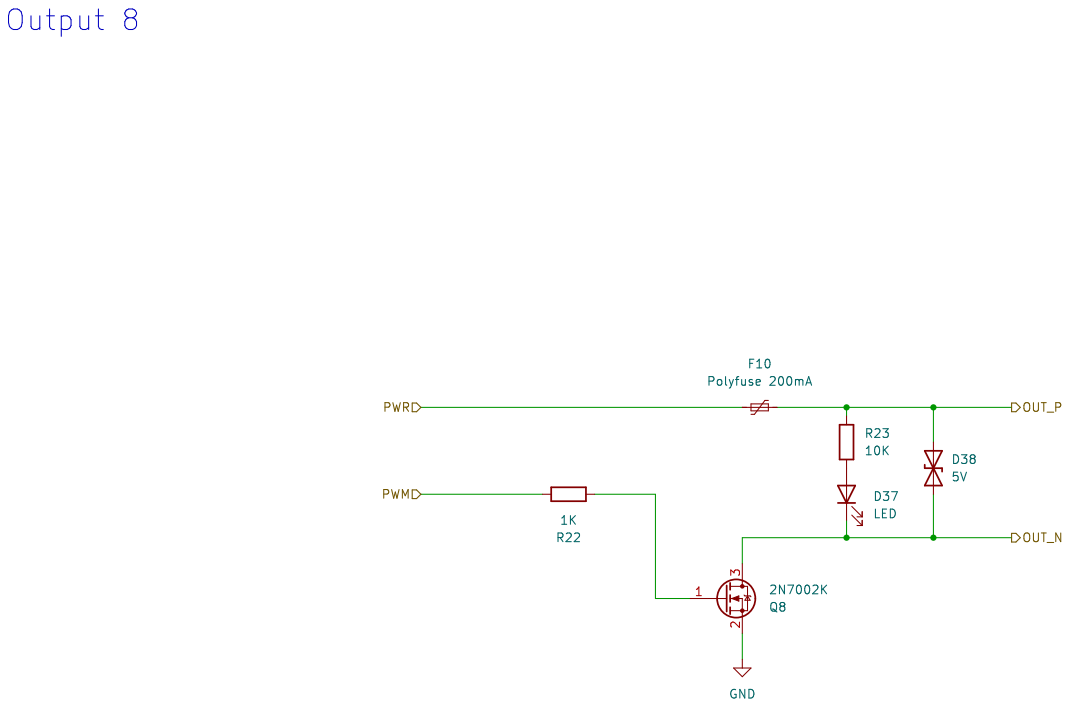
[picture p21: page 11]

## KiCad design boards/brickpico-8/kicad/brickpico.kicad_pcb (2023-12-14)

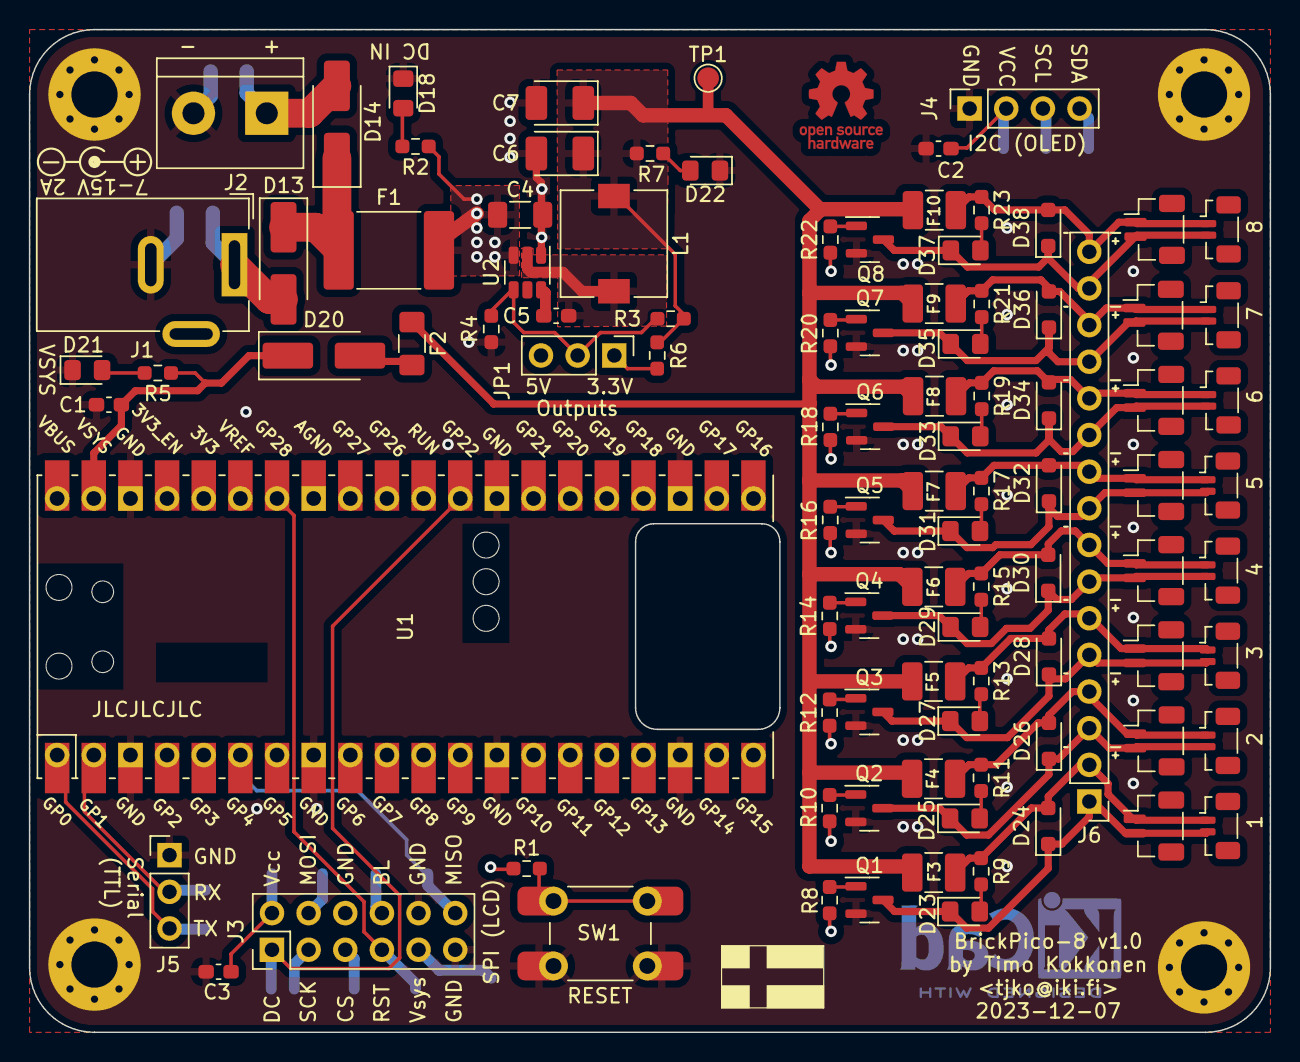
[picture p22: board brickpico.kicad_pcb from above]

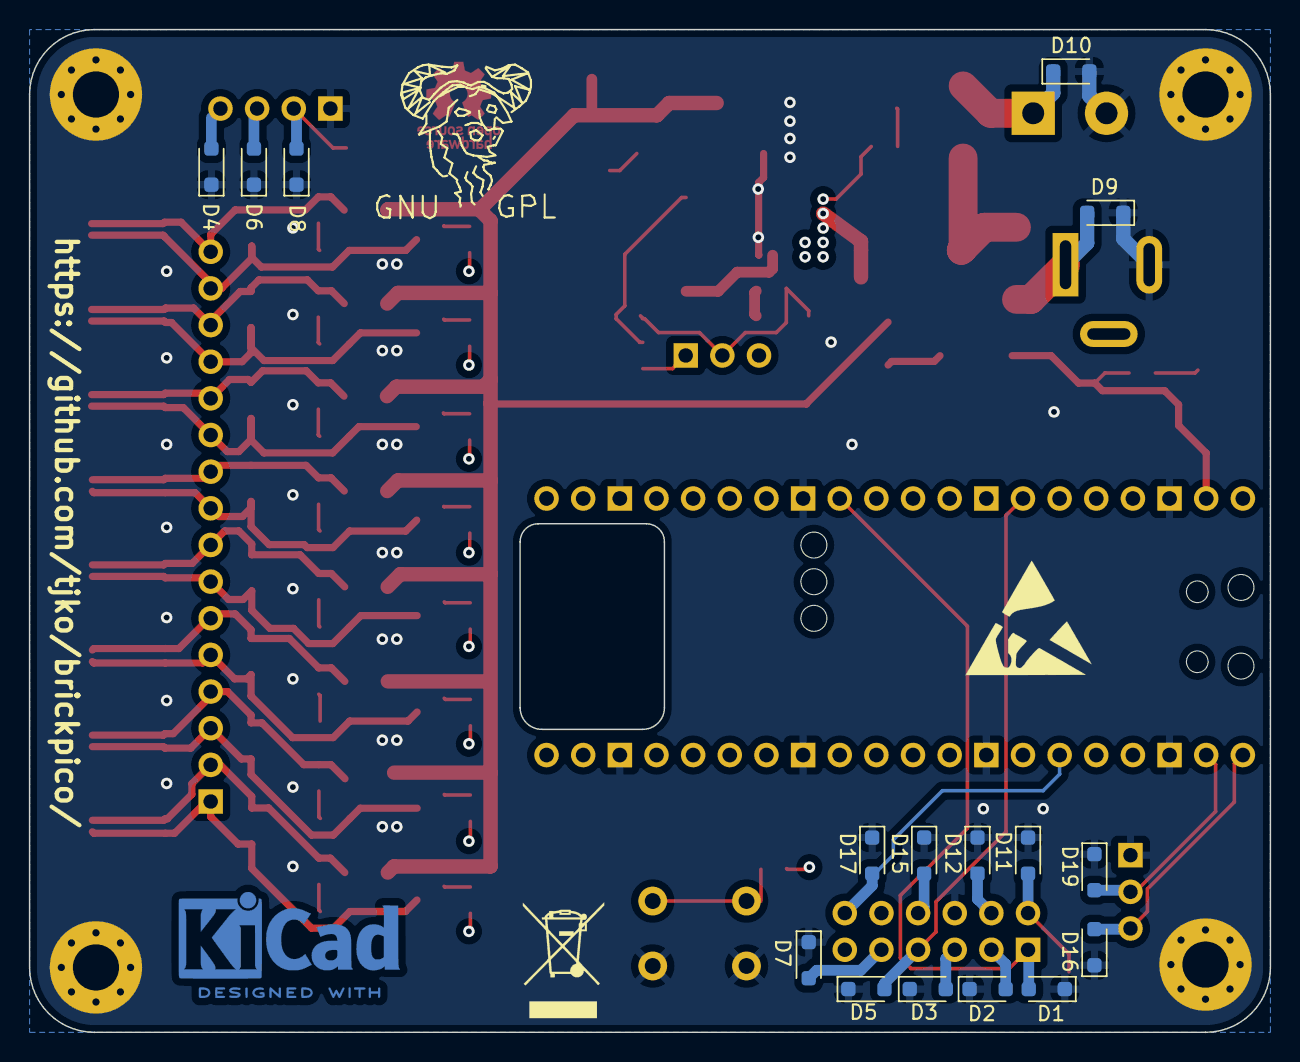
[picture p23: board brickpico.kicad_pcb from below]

Board: 4 copper layers, 86.0 x 69.5 mm, 118 parts (16 on the bottom side), 68 nets.

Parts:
C1, C2, C3, C5: 0.1uF; C_0603_1608Metric_Pad1.08x0.95mm_HandSolder
C4: 10uF 50V; C_1206_3216Metric_Pad1.33x1.80mm_HandSolder
C6, C7: 22uF 16V; CP_EIA-3528-21_Kemet-B_Pad1.50x2.35mm_HandSolder
D1, D2, D3, D4, D5, D6, D8, D11, D12, D15, D16, D17, D19: 3.3V; D_SOD-323_HandSoldering
D7, D24, D26, D28, D30, D32, D34, D36, D38: 5V; D_SOD-323_HandSoldering
D9, D10: 12V; D_SOD-323_HandSoldering
D13, D14: SK54A-LTP; D_SMA_Handsoldering
D18, D21, D22, D23, D25, D27, D29, D31, D33, D35, D37: LED; LED_0805_2012Metric_Pad1.15x1.40mm_HandSolder
D20: SM5819PL 1A; D_SMA_Handsoldering
F1: Polyfuse 3A; Fuse_2920_7451Metric_Pad2.10x5.45mm_HandSolder
F2: Polyfuse 500mA; Fuse_1206_3216Metric_Pad1.42x1.75mm_HandSolder
F3, F4, F5, F6, F7, F8, F9, F10: Polyfuse 200mA; Fuse_1210_3225Metric_Pad1.42x2.65mm_HandSolder
H1, H2, H3, H4: MountingHole_Pad; MountingHole_3.2mm_M3_Pad_Via
J1: DC Connector; BarrelJack_Wuerth_6941xx301002
J2: Terminal Block; TerminalBlock_bornier-2_P5.08mm
J3: SPI (LCD); PinHeader_2x06_P2.54mm_Vertical
J4: I2C (OLED); PinSocket_1x04_P2.54mm_Vertical
J5: Serial (TTL); PinHeader_1x03_P2.54mm_Vertical
J6: Conn_01x16; PinHeader_1x16_P2.54mm_Vertical
J7, J8, J9, J10, J11, J12, J13, J14: JST SUR; JST_SUR_BM02B-SURS-TF_1x02-1MP_P0.80mm_Vertical
J15, J16, J17, J18, J19, J20, J21, J22: JST SRS; JST_SH_BM02B-SRSS-TB_1x02-1MP_P1.00mm_Vertical
JP1: Conn_01x03; PinHeader_1x03_P2.54mm_Vertical
L1: 3.3uH; L_7.3x7.3_H3.5_HandSolder
Q1, Q2, Q3, Q4, Q5, Q6, Q7, Q8: 2N7002K; SOT-23
R1, R8, R10, R12, R14, R16, R18, R20, R22: 1K; R_0603_1608Metric_Pad0.98x0.95mm_HandSolder
R2: 49.9K; R_0603_1608Metric_Pad0.98x0.95mm_HandSolder
R3: 56.2K; R_0603_1608Metric_Pad0.98x0.95mm_HandSolder
R4, R5, R7, R9, R11, R13, R15, R17, R19, R21, R23: 10K; R_0603_1608Metric_Pad0.98x0.95mm_HandSolder
R6: 82K; R_0603_1608Metric_Pad0.98x0.95mm_HandSolder
SW1: Reset; SW_PUSH_6mm_SMD_2
TP1: TestPoint; TestPoint_Pad_D1.5mm
U1: Pico; RPi_Pico_PicoW_SMD_TH
U2: AP62300TWU; TSOT-26

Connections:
3V3: C2.2, C3.1, D8.2 (A2), D11.2 (A2), D15.2 (A2), J3.2, J3.8, J4.2, U1.36 (3V3)
/LED Connectors/Output 1/OUT_N: D23.1 (K), D24.1 (A1), J6.1, J7.2, J15.2, Q1.3 (D)
/LED Connectors/Output 1/OUT_P: D24.2 (A2), F3.2, J6.2, J7.1, J15.1, R9.1
/LED Connectors/Output 2/OUT_N: D25.1 (K), D26.1 (A1), J6.3, J8.2, J16.2, Q2.3 (D)
/LED Connectors/Output 2/OUT_P: D26.2 (A2), F4.2, J6.4, J8.1, J16.1, R11.1
/LED Connectors/Output 3/OUT_N: D27.1 (K), D28.1 (A1), J6.5, J9.2, J17.2, Q3.3 (D)
/LED Connectors/Output 3/OUT_P: D28.2 (A2), F5.2, J6.6, J9.1, J17.1, R13.1
/LED Connectors/Output 4/OUT_N: D29.1 (K), D30.1 (A1), J6.7, J10.2, J18.2, Q4.3 (D)
/LED Connectors/Output 4/OUT_P: D30.2 (A2), F6.2, J6.8, J10.1, J18.1, R15.1
/LED Connectors/Output 5/OUT_N: D31.1 (K), D32.1 (A1), J6.9, J11.2, J19.2, Q5.3 (D)
/LED Connectors/Output 5/OUT_P: D32.2 (A2), F7.2, J6.10, J11.1, J19.1, R17.1
/LED Connectors/Output 6/OUT_N: D33.1 (K), D34.1 (A1), J6.11, J12.2, J20.2, Q6.3 (D)
/LED Connectors/Output 6/OUT_P: D34.2 (A2), F8.2, J6.12, J12.1, J20.1, R19.1
/LED Connectors/Output 7/OUT_N: D35.1 (K), D36.1 (A1), J6.13, J13.2, J21.2, Q7.3 (D)
/LED Connectors/Output 7/OUT_P: D36.2 (A2), F9.2, J6.14, J13.1, J21.1, R21.1
/LED Connectors/Output 8/OUT_N: D37.1 (K), D38.1 (A1), J6.15, J14.2, J22.2, Q8.3 (D)
/LED Connectors/Output 8/OUT_P: D38.2 (A2), F10.2, J6.16, J14.1, J22.1, R23.1
CS: D3.2 (A2), J3.5, U1.7 (GPIO5)
DC: D1.2 (A2), J3.1, U1.29 (GPIO22)
DC_IN: C4.2, F1.2, R2.1, U2.3 (IN)
GND: C1.2, C2.1, C3.2, C4.1, C6.2, C7.2, D1.1 (A1), D2.1 (A1), D3.1 (A1), D4.1 (A1), D5.1 (A1), D6.1 (A1), D7.1 (A1), D8.1 (A1), D9.1 (A1), D10.2 (A2), D11.1 (A1), D12.1 (A1), D15.1 (A1), D16.1 (A1), D17.1 (A1), D18.1 (K), D19.1 (A1), D21.1 (K), D22.1 (K), H1.1, H2.1, H3.1, H4.1, J1.2, J2.2, J3.6, J3.10, J3.11, J4.1, J5.1, Q1.2 (S), Q2.2 (S), Q3.2 (S), Q4.2 (S), Q5.2 (S), Q6.2 (S), Q7.2 (S), Q8.2 (S), R4.1, SW1.2, U1.3 (GND), U1.8 (GND), U1.13 (GND), U1.18 (GND), U1.23 (GND), U1.28 (GND), U1.38 (GND), U2.1 (GND)
LED_PWR_1: C6.1, C7.1, F2.1, F3.1, F4.1, F5.1, F6.1, F7.1, F8.1, F9.1, F10.1, L1.2, R3.2, R6.2, R7.1, TP1.1
MISO: D17.2 (A2), J3.12, U1.6 (GPIO4)
MOSI: D12.2 (A2), J3.4, U1.5 (GPIO3)
unnamed: D10.1 (A1), D14.2 (A), J2.1
unnamed: D9.2 (A2), D13.2 (A), J1.1
unnamed: D13.1 (K), D14.1 (K), F1.1
unnamed: D18.2 (A), R2.2
unnamed: D20.2 (A), F2.2
unnamed: D21.2 (A), R5.2
unnamed: D22.2 (A), R7.2
unnamed: D23.2 (A), R9.2
unnamed: D25.2 (A), R11.2
unnamed: D27.2 (A), R13.2
unnamed: D29.2 (A), R15.2
unnamed: D31.2 (A), R17.2
unnamed: D33.2 (A), R19.2
unnamed: D35.2 (A), R21.2
unnamed: D37.2 (A), R23.2
unnamed: JP1.1 (A), R6.1
unnamed: JP1.2 (C), R3.1, R4.2, U2.4 (FB)
unnamed: Q1.1 (G), R8.1
unnamed: Q2.1 (G), R10.1
unnamed: Q3.1 (G), R12.1
unnamed: Q4.1 (G), R14.1
unnamed: Q5.1 (G), R16.1
unnamed: Q6.1 (G), R18.1
unnamed: Q7.1 (G), R20.1
unnamed: Q8.1 (G), R22.1
unnamed: R1.2, SW1.1
unnamed: R1.1, U1.30 (RUN)
unnamed: C5.1, U2.6 (BST)
unnamed: C5.2, L1.1, U2.2 (SW)
PWM0A: R8.2, U1.21 (GPIO16)
PWM0B: R10.2, U1.22 (GPIO17)
PWM1A: R12.2, U1.24 (GPIO18)
PWM1B: R14.2, U1.25 (GPIO19)
PWM2A: R16.2, U1.26 (GPIO20)
PWM2B: R18.2, U1.27 (GPIO21)
PWM3A: R20.2, U1.9 (GPIO6)
PWM3B: R22.2, U1.10 (GPIO7)
RST: D5.2 (A2), J3.7, U1.34 (GPIO28_ADC2)
RX: D19.2 (A2), J5.2, U1.2 (GPIO1)
SCK: D2.2 (A2), J3.3, U1.4 (GPIO2)
SCL: D6.2 (A2), J4.3, U1.32 (GPIO27_ADC1)
SDA: D4.2 (A2), J4.4, U1.31 (GPIO26_ADC0)
TX: D16.2 (A2), J5.3, U1.1 (GPIO0)
VSYS: C1.1, D7.2 (A2), D20.1 (K), J3.9, R5.1, U1.39 (VSYS)

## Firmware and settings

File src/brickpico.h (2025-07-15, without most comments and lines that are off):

#define BRICKPICO_H 1
#include "config.h"
#include "log.h"
#include <time.h>
#include "pico/mutex.h"
#ifdef LIB_PICO_CYW43_ARCH
#define WIFI_SUPPORT 1
#include "lwip/ip_addr.h"
#endif
#include "effects.h"
#include "ringbuffer.h"
#ifndef BRICKPICO_MODEL
#error unknown board model
#endif
#define OUTPUT_MAX_COUNT         16
#define VSENSOR_MAX_COUNT        8
#define VSENSOR_SOURCE_MAX_COUNT 8
#define VSENSOR_COUNT            8
#define MAX_NAME_LEN           64
#define MAX_MAP_POINTS         32
#define MAX_GPIO_PINS          32
#define WIFI_SSID_MAX_LEN      32
#define WIFI_PASSWD_MAX_LEN    64
#define WIFI_COUNTRY_MAX_LEN   3
#define MQTT_MAX_TOPIC_LEN            49
#define MQTT_MAX_USERNAME_LEN         81
#define MQTT_MAX_PASSWORD_LEN         65
#define DEFAULT_MQTT_STATUS_INTERVAL  600
#define DEFAULT_MQTT_TEMP_INTERVAL    60
#define DEFAULT_MQTT_PWR_INTERVAL     600
#define DEFAULT_MQTT_PWM_INTERVAL     600
#define SSH_MAX_PUB_KEYS  4
#define MAX_USERNAME_LEN  16
#define MAX_PWHASH_LEN    128
#ifdef NDEBUG
#define WATCHDOG_ENABLED       1
#define WATCHDOG_REBOOT_DELAY  15000
#endif
#define I2C_DEFAULT_SPEED   1000000L
#define SPI_DEFAULT_SPEED  30000000L
#define MAX_EVENT_NAME_LEN     30
#define MAX_EVENT_COUNT        20
#define BRICKPICO_FS_SIZE  (256*1024)
#define BRICKPICO_FS_OFFSET  (PICO_FLASH_SIZE_BYTES - BRICKPICO_FS_SIZE)
enum timer_action_types {
	ACTION_NONE = 0,
	ACTION_ON = 1,
	ACTION_OFF = 2,
};
#define TIMER_ACTION_ENUM_MAX 2
enum vsensor_modes {
	VSMODE_MANUAL = 0,
	VSMODE_MAX = 1,
	VSMODE_MIN = 2,
	VSMODE_AVG = 3,
	VSMODE_DELTA = 4,
	VSMODE_I2C = 5,
	VSMODE_PICOTEMP = 6,
};
#define VSMODE_ENUM_MAX 6
struct ssh_public_key {
	char username[MAX_USERNAME_LEN + 1];
	char type[32 + 1];
	char name[32 + 1];
	uint8_t pubkey[128];
	uint16_t pubkey_size;
};
struct timer_event {
	char name[MAX_EVENT_NAME_LEN];
	int8_t minute;
	int8_t hour;
	uint8_t wday;
	enum timer_action_types action;
	uint16_t mask;
};
struct pwm_output {
	char name[MAX_NAME_LEN];
	uint8_t min_pwm;
	uint8_t max_pwm;
	uint8_t default_pwm;
	uint8_t default_state;
	uint8_t type;
	enum light_effect_types effect;
	void *effect_ctx;
};
struct vsensor_input {
	char name[MAX_NAME_LEN];
	enum vsensor_modes mode;
	float default_temp;
	int32_t timeout;
	uint8_t sensors[VSENSOR_SOURCE_MAX_COUNT];
	uint8_t i2c_type;
	uint8_t i2c_addr;
};
struct brickpico_config {
	struct pwm_output outputs[OUTPUT_MAX_COUNT];
	struct vsensor_input vsensors[VSENSOR_MAX_COUNT];
	bool local_echo;
	uint8_t led_mode;
	char display_type[64];
	char display_theme[16];
	char display_logo[16];
	char display_layout_r[64];
	char gamma[16];
	char name[32];
	char timezone[64];
	bool spi_active;
	bool serial_active;
	uint32_t i2c_speed;
	uint pwm_freq;
	struct timer_event events[MAX_EVENT_COUNT];
	uint8_t event_count;
	double adc_ref_voltage;
	double temp_offset;
	double temp_coefficient;
#ifdef WIFI_SUPPORT
	char wifi_ssid[WIFI_SSID_MAX_LEN + 1];
	char wifi_passwd[WIFI_PASSWD_MAX_LEN + 1];
	char wifi_country[WIFI_COUNTRY_MAX_LEN + 1];
	char wifi_auth_mode[16];
	uint8_t wifi_mode;
	char hostname[32];
	ip_addr_t syslog_server;
	ip_addr_t ntp_server;
	ip_addr_t ip;
	ip_addr_t netmask;
	ip_addr_t gateway;
	char mqtt_server[32];
	uint32_t mqtt_port;
	bool mqtt_tls;
	bool mqtt_allow_scpi;
	char mqtt_user[MQTT_MAX_USERNAME_LEN + 1];
	char mqtt_pass[MQTT_MAX_PASSWORD_LEN + 1];
	char mqtt_cmd_topic[MQTT_MAX_TOPIC_LEN + 1];
	char mqtt_resp_topic[MQTT_MAX_TOPIC_LEN + 1];
	char mqtt_err_topic[MQTT_MAX_TOPIC_LEN + 1];
	char mqtt_warn_topic[MQTT_MAX_TOPIC_LEN + 1];
	char mqtt_status_topic[MQTT_MAX_TOPIC_LEN + 1];
	char mqtt_pwm_topic[MQTT_MAX_TOPIC_LEN + 1];
	char mqtt_temp_topic[MQTT_MAX_TOPIC_LEN + 1];
	uint32_t mqtt_status_interval;
	uint32_t mqtt_pwm_interval;
	uint32_t mqtt_temp_interval;
	uint16_t mqtt_pwm_mask;
	char mqtt_ha_discovery_prefix[32 + 1];
	bool telnet_active;
	bool telnet_auth;
	bool telnet_raw_mode;
	uint32_t telnet_port;
	char telnet_user[MAX_USERNAME_LEN + 1];
	char telnet_pwhash[MAX_PWHASH_LEN + 1];
	bool ssh_active;
	bool ssh_auth;
	uint32_t ssh_port;
	char ssh_user[MAX_USERNAME_LEN + 1];
	char ssh_pwhash[MAX_PWHASH_LEN + 1];
	struct ssh_public_key ssh_pub_keys[SSH_MAX_PUB_KEYS];
#endif
	void *i2c_context[VSENSOR_MAX_COUNT];
};
struct brickpico_fw_settings {
	bool safemode;
	int  bootdelay;
};
struct brickpico_state {
	uint8_t pwm[OUTPUT_MAX_COUNT];
	uint8_t pwr[OUTPUT_MAX_COUNT];
	float temp;
	float temp_prev;
	float vtemp[VSENSOR_MAX_COUNT];
	float vhumidity[VSENSOR_MAX_COUNT];
	float vpressure[VSENSOR_MAX_COUNT];
	absolute_time_t vtemp_updated[VSENSOR_MAX_COUNT];
	float vtemp_prev[VSENSOR_MAX_COUNT];
};
struct persistent_memory_block {
	uint32_t id;
	struct timespec saved_time;
	uint64_t uptime;
	uint64_t prev_uptime;
	u8_ringbuffer_t log_rb;
	uint32_t crc32;
	uint8_t log[8192];
};
extern u8_ringbuffer_t *log_rb;
extern struct persistent_memory_block *persistent_mem;
extern struct brickpico_state *brickpico_state;
extern bool rebooted_by_watchdog;
extern mutex_t *pmem_mutex;
extern mutex_t *state_mutex;
void update_persistent_memory_crc();
void update_persistent_memory();
void update_display_state();
void update_core1_state();
void set_binary_info(struct brickpico_fw_settings *settings);
void process_command(struct brickpico_state *state, struct brickpico_config *config, char *command);
int cmd_version(const char *cmd, const char *args, int query, char *prev_cmd);
int last_command_status();
extern mutex_t *config_mutex;
extern const struct brickpico_config *cfg;
enum vsensor_modes str2vsmode(const char *s);
const char* vsmode2str(enum vsensor_modes mode);
#if WIFI_SUPPORT
int str_to_ssh_pubkey(const char *s, struct ssh_public_key *pk);
const char* ssh_pubkey_to_str(const struct ssh_public_key *pk, char *s, size_t s_len);
#endif
void read_config(bool use_default_config);
void save_config();
void delete_config();
void print_config();
void display_init();
void clear_display();
void display_message(int rows, const char **text_lines);
void display_status(const struct brickpico_state *state, const struct brickpico_config *config);
void oled_display_init();
void oled_clear_display();
void oled_display_status(const struct brickpico_state *state, const struct brickpico_config *conf);
void oled_display_message(int rows, const char **text_lines);
int str2effect(const char *s);
const char* effect2str(enum light_effect_types effect);
void* effect_parse_args(enum light_effect_types effect, const char *args);
char* effect_print_args(enum light_effect_types effect, void *ctx);
uint8_t light_effect(enum light_effect_types effect, void *ctx, uint64_t t, uint8_t pwm, uint8_t pwr);
void lfs_setup(bool multicore);
int flash_format(bool multicore);
int flash_read_file(char **bufptr, uint32_t *sizeptr, const char *filename);
int flash_write_file(const char *buf, uint32_t size, const char *filename);
int flash_delete_file(const char *filename);
int flash_rename_file(const char *oldname, const char *newname);
int flash_copy_file(const char *srcname, const char *dstname, bool overwrite);
int flash_file_size(const char *filename);
int flash_get_fs_info(size_t *size, size_t *free, size_t *files,
		size_t *directories, size_t *filesizetotal);
int flash_list_directory(const char *path, bool recursive);
void print_rp2040_flashinfo();
void network_init();
void network_mac();
void network_poll();
void network_status();
void set_pico_system_time(long unsigned int sec);
const char *network_ip();
const char *network_hostname();
#if WIFI_SUPPORT
bool wifi_get_auth_type(const char *name, uint32_t *type);
const char* wifi_auth_type_name(uint32_t type);
void brickpico_setup_http_handlers();
void tcpserver_init();
void sshserver_init();
void sshserver_disconnect();
void sshserver_who();
void ssh_list_pkeys();
int ssh_create_pkey(const char* args);
int ssh_delete_pkey(const char* args);
int ssh_get_pkey(int index, char** buf_ptr, uint32_t* buf_size_ptr, const char** name_ptr);
void brickpico_setup_mqtt_client();
int brickpico_mqtt_client_active();
int brickpico_mqtt_client_connected();
void brickpico_mqtt_publish();
void brickpico_mqtt_publish_duty();
void brickpico_mqtt_publish_temp();
void brickpico_mqtt_scpi_command();
void brickpico_mqtt_poll();
#endif
void scan_i2c_bus();
void display_i2c_status();
void setup_i2c_bus(struct brickpico_config *config);
int i2c_read_temps(const struct brickpico_config *config, struct brickpico_state *st);
int read_pem_file(char *buf, uint32_t size, uint32_t timeout, bool append);
#ifdef WIFI_SUPPORT
struct altcp_tls_config* tls_server_config();
#endif
void setup_pwm_inputs();
void setup_pwm_outputs();
void set_pwm_duty_cycle(uint out, float duty);
void set_pwm_lightness(uint out, uint lightness);
float get_pwm_duty_cycle(uint fan);
void get_pwm_duty_cycles(const struct brickpico_config *config);
int str2log_priority(const char *pri);
const char* log_priority2str(int pri);
int str2log_facility(const char *facility);
const char* log_facility2str(int facility);
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

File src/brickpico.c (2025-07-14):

/* brickpico.c
   Copyright (C) 2023-2025 Timo Kokkonen <tjko@iki.fi>

   SPDX-License-Identifier: GPL-3.0-or-later

   This file is part of BrickPico.

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
   You should have received a copy of the GNU General Public License
   along with BrickPico. If not, see <https://www.gnu.org/licenses/>.
*/

#include <stdio.h>
#include <stdlib.h>
#include <string.h>
#include <math.h>
#include <malloc.h>
#include "pico/stdlib.h"
#include "pico/mutex.h"
#include "pico/multicore.h"
#include "pico/util/datetime.h"
#include "pico/aon_timer.h"
#ifdef LIB_PICO_CYW43_ARCH
#include "pico/cyw43_arch.h"
#endif
#include "hardware/adc.h"
#include "hardware/gpio.h"
#include "hardware/pwm.h"
#include "hardware/clocks.h"
#include "hardware/watchdog.h"
#include "hardware/vreg.h"
#include "ringbuffer.h"
#include "brickpico.h"


static struct brickpico_config core1_config;
static struct brickpico_state core1_state;
static struct brickpico_state transfer_state;
static struct brickpico_state system_state;
struct brickpico_state *brickpico_state = &system_state;
static struct brickpico_fw_settings system_settings;
const struct brickpico_fw_settings *firmware_settings = &system_settings;

struct persistent_memory_block __uninitialized_ram(persistent_memory);
struct persistent_memory_block *persistent_mem = &persistent_memory;
u8_ringbuffer_t *log_rb = NULL;

#define PERSISTENT_MEMORY_ID 0xbaddecaf
#define PERSISTENT_MEMORY_CRC_LEN offsetof(struct persistent_memory_block, crc32)

auto_init_mutex(pmem_mutex_inst);
mutex_t *pmem_mutex = &pmem_mutex_inst;
auto_init_mutex(state_mutex_inst);
mutex_t *state_mutex = &state_mutex_inst;
bool rebooted_by_watchdog = false;


void update_persistent_memory_crc()
{
	struct persistent_memory_block *m = persistent_mem;

	m->crc32 = xcrc32((unsigned char*)m, PERSISTENT_MEMORY_CRC_LEN, 0);
}

void init_persistent_memory()
{
	struct persistent_memory_block *m = persistent_mem;
	uint32_t crc;

	if (m->id == PERSISTENT_MEMORY_ID) {
		crc = xcrc32((unsigned char*)m, PERSISTENT_MEMORY_CRC_LEN, 0);
		if (crc == m->crc32) {
			printf("Found persistent memory block\n");
			if (m->saved_time.tv_sec > 0)
				aon_timer_start(&m->saved_time);
			if (m->uptime) {
				m->prev_uptime = m->uptime;
				update_persistent_memory_crc();
			}
			return;
		}
		printf("Found corrupt persistent memory block"
			" (CRC-32 mismatch  %08lx != %08lx)\n", crc, m->crc32);
	}

	printf("Initializing persistent memory block...\n");
	memset(m, 0, sizeof(*m));
	m->id = PERSISTENT_MEMORY_ID;
	u8_ringbuffer_init(&m->log_rb, m->log, sizeof(m->log));
	update_persistent_memory_crc();
}

void update_persistent_memory()
{
	struct persistent_memory_block *m = persistent_mem;
	struct timespec t;

	if (mutex_enter_timeout_us(pmem_mutex, 100)) {
		if (aon_timer_is_running()) {
			aon_timer_get_time(&t);
			m->saved_time = t;
		}
		m->uptime = to_us_since_boot(get_absolute_time());
		update_persistent_memory_crc();
		mutex_exit(pmem_mutex);
	} else {
		log_msg(LOG_DEBUG, "update_persistent_memory(): Failed to get pmem_mutex");
	}
}

void boot_reason()
{
#if PICO_RP2040
	printf("     CHIP_RESET: %08lx\n", vreg_and_chip_reset_hw->chip_reset);
#endif
	printf("WATCHDOG_REASON: %08lx\n", watchdog_hw->reason);
}

void setup()
{
	char buf[32];
	int i = 0;


	stdio_usb_init();
	/* Wait a while for USB Serial to connect... */
	while (i++ < 40) {
		if (stdio_usb_connected())
			break;
		sleep_ms(50);
	}

	if (firmware_settings->bootdelay > 0)
		sleep_ms(firmware_settings->bootdelay * 1000);

	lfs_setup(false);
	read_config(firmware_settings->safemode);

#if TTL_SERIAL > 0
	stdio_uart_init_full(TTL_SERIAL_UART,
			TTL_SERIAL_SPEED, TX_PIN, RX_PIN);
	sleep_ms(5);
#endif
	printf("\n\n");
#ifndef NDEBUG
	boot_reason();
#endif
	if (watchdog_enable_caused_reboot()) {
		printf("[Rebooted by watchdog]\n");
		rebooted_by_watchdog = true;
	}
	printf("\n");

	/* Run "SYStem:VERsion" command... */
	cmd_version(NULL, NULL, 0, NULL);
	printf("Hardware Model: BRICKPICO-%s\n", BRICKPICO_MODEL);
	printf("         Board: %s\n", PICO_BOARD);
	printf("           MCU: %s @ %0.0fMHz\n",
		rp2040_model_str(),
		clock_get_hz(clk_sys) / 1000000.0);
	printf(" Serial Number: %s\n\n", pico_serial_str());

	init_persistent_memory();
	log_rb = &persistent_mem->log_rb;
	printf("\n");
	if (firmware_settings->safemode)
		printf("*** Booting into Safe Mode ***\n\n");

	log_msg(LOG_NOTICE, "System starting...");
	if (persistent_mem->prev_uptime) {
		log_msg(LOG_NOTICE, "Uptime before soft reset: %llus\n",
			persistent_mem->prev_uptime / 1000000);
	}
	if (aon_timer_is_running()) {
		struct timespec ts;
		aon_timer_get_time(&ts);
		log_msg(LOG_NOTICE, "RTC clock time: %s",
			time_t_to_str(buf, sizeof(buf), timespec_to_time_t(&ts)));
	}

	setup_i2c_bus((struct brickpico_config *)cfg);
	display_init();
	network_init(&system_state);

	/* Enable ADC */
	log_msg(LOG_NOTICE, "Initialize ADC...");
	adc_init();
	adc_set_temp_sensor_enabled(true);

	/* Setup GPIO pins... */
	log_msg(LOG_NOTICE, "Initialize GPIO...");

	/* Initialize status LED... */
	if (LED_PIN > 0) {
		gpio_init(LED_PIN);
		gpio_set_dir(LED_PIN, GPIO_OUT);
		gpio_put(LED_PIN, 0);
	}
#ifdef LIB_PICO_CYW43_ARCH
	/* On pico_w, LED is connected to the radio GPIO... */
	cyw43_arch_gpio_put(CYW43_WL_GPIO_LED_PIN, 0);
#endif

	/* Configure PWM pins... */
	setup_pwm_outputs();

	for (i = 0; i < OUTPUT_COUNT; i++) {
		uint8_t duty = cfg->outputs[i].default_pwm;
		uint8_t state = cfg->outputs[i].default_state;
		set_pwm_duty_cycle(i, (state ? duty : 0));
		brickpico_state->pwm[i] = duty;
		brickpico_state->pwr[i] = state;
	}

	/* Set Timezone */
	if (strlen(cfg->timezone) > 1) {
		log_msg(LOG_NOTICE, "Set Timezone: %s", cfg->timezone);
		setenv("TZ", cfg->timezone, 1);
		tzset();
	}

	log_msg(LOG_NOTICE, "System initialization complete.");
}


void clear_state(struct brickpico_state *s)
{
	int i;

	for (i = 0; i < OUTPUT_MAX_COUNT; i++) {
		s->pwm[i] = 0;
		s->pwr[i] = 0;
	}
	s->temp = 0.0;
	s->temp_prev = 0.0;

	for (i = 0; i < VSENSOR_MAX_COUNT; i++) {
		s->vtemp[i] = 0.0;
		s->vtemp_prev[i] = 0.0;
		s->vhumidity[i] = -1.0;
		s->vpressure[i] = -1.0;
		s->vtemp_updated[i] = from_us_since_boot(0);
	}

}


void update_core1_state()
{
	mutex_enter_blocking(state_mutex);
	memcpy(&transfer_state, &system_state, sizeof(transfer_state));
	mutex_exit(state_mutex);
}

void core1_main()
{
	struct brickpico_config *config = &core1_config;
	struct brickpico_state *state = &core1_state;
	struct brickpico_state prev_state;
	absolute_time_t t_now, t_last, t_config, t_state, t_tick, t_effect;
	int64_t max_delta = 0;
	int64_t delta;
	uint8_t pwm[OUTPUT_MAX_COUNT];

	log_msg(LOG_INFO, "core1: started...");
	memset(pwm, 0, sizeof(pwm));

	/* Allow core0 to pause this core... */
	multicore_lockout_victim_init();

	clear_state(&prev_state);
	t_last = t_effect = t_config = t_state = t_tick = get_absolute_time();

	while (1) {
		t_now = get_absolute_time();
		delta = absolute_time_diff_us(t_last, t_now);
		t_last = t_now;

		if (delta > max_delta) {
			max_delta = delta;
			log_msg(LOG_INFO, "core1: max_loop_time=%lld", max_delta);
		}

		if (time_passed(&t_tick, 60000)) {
			log_msg(LOG_DEBUG, "tick");
		}

		if (time_passed(&t_config, 4000)) {
			/* Attempt to update (read) config from core0 */
			if (mutex_enter_timeout_us(config_mutex, 100)) {
				memcpy(config, cfg, sizeof(*config));
				mutex_exit(config_mutex);
			} else {
				log_msg(LOG_INFO, "failed to get config_mutex");
			}
		}

		if (time_passed(&t_state, 250)) {
			/* Attempt to update (read) state from core0 */
			if (mutex_enter_timeout_us(state_mutex, 100)) {
				memcpy(&prev_state, state, sizeof(prev_state));
				memcpy(state, &transfer_state, sizeof(*state));
				mutex_exit(state_mutex);

				/* Check for changes... */
				for(int i = 0; i < OUTPUT_COUNT; i++) {
					if (prev_state.pwm[i] != state->pwm[i]) {
						log_msg(LOG_INFO, "output%d: PWM change '%u' -> '%u'", i + 1,
							prev_state.pwm[i], state->pwm[i]);
					}
					if (prev_state.pwr[i] != state->pwr[i]) {
						log_msg(LOG_INFO, "output%d: state change %u -> %u", i + 1,
							prev_state.pwr[i], state->pwr[i]);
					}
				}
			} else {
				log_msg(LOG_INFO, "failed to get state_mutex");
			}
		}

		if (time_passed(&t_effect, 100)) {
			uint8_t new;
			uint64_t t = to_us_since_boot(get_absolute_time());

			for(int i = 0; i < OUTPUT_COUNT; i++) {
				new = light_effect(config->outputs[i].effect,
						config->outputs[i].effect_ctx,
						t, state->pwm[i],state->pwr[i]);

				if (new != pwm[i]) {
					set_pwm_lightness(i, new);
					pwm[i] = new;
				}
			}
		}
	}
}


int main()
{
	absolute_time_t ABSOLUTE_TIME_INITIALIZED_VAR(t_led, 0);
	absolute_time_t ABSOLUTE_TIME_INITIALIZED_VAR(t_network, 0);
	absolute_time_t t_now, t_last, t_display, t_timer, t_temp, t_i2c_temp, t_ram;
	uint8_t led_state = 0;
	int64_t max_delta = 0;
	int64_t delta;
	int c;
	char input_buf[1024 + 1];
	int i_ptr = 0;
	int i2c_temp_delay = 1000;


	set_binary_info(&system_settings);
	clear_state(&system_state);
	clear_state(&transfer_state);

	/* Initialize MCU and other hardware... */
	if (get_debug_level() >= 2)
		print_mallinfo();
	setup();
	if (get_debug_level() >= 2)
		print_mallinfo();

	/* Start second core (core1)... */
	memcpy(&core1_config, cfg, sizeof(core1_config));
	memcpy(&core1_state, &system_state, sizeof(core1_state));
	update_core1_state();
	multicore_launch_core1(core1_main);

#if WATCHDOG_ENABLED
	watchdog_enable(WATCHDOG_REBOOT_DELAY, 1);
	log_msg(LOG_NOTICE, "Watchdog enabled.");
#endif

	t_last = get_absolute_time();
	t_ram = t_i2c_temp = t_temp = t_timer = t_display = t_last;

	while (1) {
		t_now = get_absolute_time();
		delta = absolute_time_diff_us(t_last, t_now);
		t_last = t_now;

		if (delta > max_delta || delta > 1000000) {
			max_delta = delta;
			log_msg(LOG_INFO, "core0: max_loop_time=%lld", max_delta);
		}

		if (time_passed(&t_network, 100)) {
			network_poll();
		}
		if (time_passed(&t_ram, 1000)) {
			update_persistent_memory();
		}

		/* Toggle LED every 1000ms */
		if (time_passed(&t_led, 1000)) {
			if (cfg->led_mode == 0) {
				/* Slow blinking */
				led_state = (led_state > 0 ? 0 : 1);
			} else if (cfg->led_mode == 1) {
				/* Always on */
				led_state = 1;
			} else {
				/* Always off */
				led_state = 0;
			}
#if LED_PIN > 0
			gpio_put(LED_PIN, led_state);
#endif
#ifdef LIB_PICO_CYW43_ARCH
			cyw43_arch_gpio_put(CYW43_WL_GPIO_LED_PIN, led_state);
#endif
		}

		/* Update display every 1000ms */
		if (time_passed(&t_display, 1000)) {
			update_core1_state();
			display_status(brickpico_state, cfg);
		}

		/* Check for timer events */
		if (time_passed(&t_timer, 10000)) {
			handle_timer_events(cfg, brickpico_state);
		}

		/* Check temperature */
		if (time_passed(&t_temp, 4000)) {
			update_temp(cfg, brickpico_state);
		}

		/* Poll I2C Temperature Sensors */
		if (i2c_temp_delay > 0 && time_passed(&t_i2c_temp, i2c_temp_delay)) {
			i2c_temp_delay = i2c_read_temps(cfg, brickpico_state);
		}

		/* Process any (user) input */
		while ((c = getchar_timeout_us(0)) != PICO_ERROR_TIMEOUT) {
			if (c == 0xff || c == 0x00)
				continue;
			if (c == 0x7f || c == 0x08) {
				if (i_ptr > 0) i_ptr--;
				if (cfg->local_echo) printf("\b \b");
				continue;
			}
			if (c == 10 || c == 13 || i_ptr >= sizeof(input_buf) - 1) {
				if (cfg->local_echo) printf("\r\n");
				input_buf[i_ptr] = 0;
				if (i_ptr > 0) {
					process_command(brickpico_state, (struct brickpico_config *)cfg, input_buf);
					i_ptr = 0;
					update_core1_state();
				}
				continue;
			}
			input_buf[i_ptr++] = c;
			if (cfg->local_echo) printf("%c", c);
		}
#if WATCHDOG_ENABLED
		watchdog_update();
#endif
	}
}


/* eof :-) */

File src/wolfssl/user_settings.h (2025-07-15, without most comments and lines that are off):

#define WOLFSSL_USER_SETTINGS_H
#ifdef __cplusplus
extern "C"
{
#endif
#include <stdio.h>
#include <time.h>
#define TARGET_EMBEDDED
#define WOLFCRYPT_ONLY
#define WOLFSSL_WOLFSSH
#define WOLFSSL_RPIPICO
#define WOLFSSH_SMALL_STACK
#define WOLFSSH_KEYGEN
#define WOLFSSH_ALLOW_USERAUTH_NONE
#define DEFAULT_WINDOW_SZ 4096
#define DEFAULT_MAX_PACKET_SZ 1024
#define WOLFSSL_GENERAL_ALIGNMENT 4
#define SIZEOF_LONG_LONG 8
#define SINGLE_THREADED
#define WOLFSSL_SMALL_STACK
#define WOLFSSL_USER_IO
#define SP_INT_BITS 256
#define WOLFSSL_HAVE_SP_ECC
#define WOLFSSL_SP_MATH
#define WOLFSSL_SP_MATH_ALL
#undef NO_RSA
#define NO_RSA
#undef NO_DH
#define NO_DH
#undef HAVE_ECC
#define HAVE_ECC
#define ECC_SHAMIR
#define ECC_TIMING_RESISTANT
#undef NO_AES
#define HAVE_AES_CBC
#define HAVE_AESGCM
#define GCM_TABLE_4BIT
#undef NO_DES3
#define NO_DES3
#undef HAVE_CHACHA
#undef HAVE_POLY1305
#define HAVE_CHACHA
#define HAVE_POLY1305
#define HAVE_ONE_TIME_AUTH
#undef HAVE_CURVE25519
#undef HAVE_ED25519
#define HAVE_CURVE25519
#define HAVE_ED25519
#define HAVE_ED25519_KEY_IMPORT
#define HAVE_ED25519_KEY_EXPORT
#define WOLFSSL_ED25519_STREAMING_VERIFY
#undef HAVE_CURVE448
#undef HAVE_ED448
#define HAVE_CURVE448
#define HAVE_ED448
#define WOLFSSL_SHAKE256
#undef NO_SHA
#undef NO_SHA256
#undef WOLFSSL_SHA512
#define WOLFSSL_SHA512
#undef WOLFSSL_SHA384
#define WOLFSSL_SHA384
#undef WOLFSSL_SHA3
#define WOLFSSL_SHA3
#undef NO_MD5
#define NO_MD5
#undef HAVE_HKDF
#define HAVE_HKDF
#undef WOLFSSL_CMAC
#define BENCH_EMBEDDED
#define USE_CERT_BUFFERS_256
#define USE_CERT_BUFFERS_2048
#undef DEBUG_WOLFSSL
#undef NO_ERROR_STRINGS
#define DEBUG_WOLFSSL
#define NO_WOLFSSL_MEMORY
#undef WC_NO_HASHDRBG
#define WC_NO_HASHDRBG
#undef CUSTOM_RAND_GENERATE_BLOCK
#define CUSTOM_RAND_GENERATE_BLOCK wc_pico_rng_gen_block
#undef STRING_USER
#define WOLFSSL_TLS13
#define WOLFSSL_OLD_PRIME_CHECK
#define HAVE_TLS_EXTENSIONS
#define HAVE_SUPPORTED_CURVES
#define WOLFSSL_BASE64_ENCODE
#define WOLFSSL_KEY_GEN
#define NO_SESSION_CACHE
#define WOLFSSL_IGNORE_FILE_WARN
#define NO_FILESYSTEM
#define NO_WRITEV
#define NO_MAIN_DRIVER
#define NO_DEV_RANDOM
#define NO_OLD_TLS
#define NO_PSK
#define NO_DSA
#define NO_RC4
#define NO_MD4
#define NO_PWDBASED
#ifdef __cplusplus
}
#endif

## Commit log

2023-12-13 Initial firmware image fully functional. (#1)
    Initial firmware heavily based on FanPico (https://github.com/tjko/fanpico/) functional on prototype board.
    [status.csv]
2023-12-13 Fix brickpico-8 build again.
    [8.h]
2023-12-14 Add brickpico-08 board.
    [brickpico.kicad_pcb, brickpico.kicad_sch, connectors.kicad_sch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]
2023-12-15 Add new commands: CONF:DEFAULT:PWM CONF:DEFAULT:STATE
2023-12-15 Update default board.
2023-12-19 Add bill of materials for brickpico-8.
    [bom.csv]
2023-12-19 Fix board name.
2023-12-19 Fix wront type argument to printf.
2023-12-20 Fix firmware upgrade screen text.
    [command.c]
2023-12-23 Fix timer event weekday check.
2023-12-31 Switch more commands to use generic helper functions.
2024-01-04 Update to MQTT client. (#7)
    - Support for sending per output status as well as unit temperature.
    - Updated reconnect logic.
    - Update documentation and add support subscribing error/warning topics…
    [brickpico.c, brickpico.h, command.c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]
2024-01-07 Enable HTTPS support and persistent memory to keep logs and RTC time after soft reset. (#9)
    [brickpico.c, brickpico.h, command.c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]
2024-01-07 Updated UCS Millennium Falcon png.
2024-01-13 Add PCB diagram.
2024-01-31 Add Telnet (server) support. (#11)
    - Add support for telnet (and "raw TCP") server using pico-telnetd library.
2024-02-21 Fix SYS:TELNET:AUTH and add SYS:LFS? command. (#12)
    [brickpico.h, command.c, config.c]
2024-02-21 Switch to using pico-lfs library for littlefs. (#13)
2024-03-14 Fix possible hang when initializing LFS. (#15)
    * Add new command SYS:LFS:FORMAT
    * Fix possible hang if LFS needed to be initialized during boot.
    [brickpico.c, brickpico.h, command.c]
2024-08-14 Fix memory leak when opening MQTT connections.
    [mqtt.c]
2024-12-23 Pico-SDK v2.1.0 support (#21)
    * Fixed compile issues on Pico-SDK 2.1.0
    * Update pico_telnetd and ss_oled-lib libraries.
    * Fix compiling for pico2 and pico2_w.
    * Include license files in firmware zip files.
    [brickpico.c, brickpico.h, command.c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]
2024-12-24 WiFi updates (#22)
    - Add new commands to set WiFi authentication mode:
    - SYS:WIFI:AUTHmode
    - SYS:WIFI:AUTHmode?
    - Fix possible hang if WiFi fails to connect.
    [brickpico.h, command.c, config.c]
2024-12-31 Home Assistant (MQTT Discovery) Support (#23)
    * Initial HomeAssistant MQTT Discovery support (using Device Discovery)
    * New commands:
    - SYStem:MQTT:HA:DISCovery
    - SYStem:MQTT:HA:DISCovery?
2025-01-10 Add initial Lightness/Gamma correction support. (#25)
    * Add initial Lightness/Gamma correction support.
    - SYS:GAMMA
    - SYS:GAMMA?
    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
    [brickpico.c, brickpico.h, command.c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]
2025-07-14 Add I2C sensor support. (#30)
2025-07-17 Fix temperature readings on RP2350B.
    [temp.c]
2025-08-27 Update Pico-SDK and other libraries. (#32)

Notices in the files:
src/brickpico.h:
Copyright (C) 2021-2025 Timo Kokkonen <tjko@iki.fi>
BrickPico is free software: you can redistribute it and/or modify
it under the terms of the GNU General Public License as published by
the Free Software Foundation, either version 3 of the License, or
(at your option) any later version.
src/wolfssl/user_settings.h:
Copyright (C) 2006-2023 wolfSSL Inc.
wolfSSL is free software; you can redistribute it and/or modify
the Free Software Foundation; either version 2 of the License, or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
